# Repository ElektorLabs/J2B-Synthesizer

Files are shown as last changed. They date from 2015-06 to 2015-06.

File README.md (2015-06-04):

J2B Synthesizer
===============

An open source, open hardware music synthesizer for you to enjoy.
Based on an LPC1347 32-bit ARM Cortex-M3 microcontroller, this synthesizer
uses PWM to output sound. Originally based on and inspired by the Soulsby
Atmegatron.

Software is an LPCXpresso project.

Precompiled binaries are included for several synthesizers including
one drum machine. Uploading the firmware to the microcontroller is as simple 
as copying a file to a USB stick (this works on Windows only).

Licensed as described in the diverse licenses that may be found in the
repository. Roughly they state that you are allowed to do whatever you want
with this, as long as it remains for private use. However, you are allowed
to make money from music made with the J2B Synthesizer. 

More info:

www.elektor-labs.com/j2b-synthesizer

This is Elektor project 140182, published in Elektor Magazine, January 2015.

www.elektor-magazine.com/140182

www.elektor.com

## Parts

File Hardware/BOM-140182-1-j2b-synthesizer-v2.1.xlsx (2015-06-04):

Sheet: 140182-1
BOM::140182::J2B-synthesizer::v2.0
Description | Manufacturer | Reference | Footprint | Designation | Qnt | Farnell | Digikey | RS | Price | BOM for editors
Resistor |  |  |  |  | 89 |  |  |  |  | Resistor
resistor 0R 5% 0.1W | Multicomp | MC0805S8F0000T5E | R0805 | R1, R22, R26, R45, R49, R64, R68 | 7 | 2309112 |  |  |  | R1, R22, R26, R45, R49, R64, R68 = resistor 0R 5% 0.1W
resistor 10R 5% 0.1W | Multicomp | MC 0.1W 0805 5% 10R | M0805 | R76, R84 | 2 | 9333690 |  |  |  | R76, R84 = resistor 10R 5% 0.1W
resistor 33R 5% 0.1W | Multicomp | MC 0.1W 0805 5% 33R | R0805 | R3, R4 | 2 | 9334343 |  |  |  | R3, R4 = resistor 33R 5% 0.1W
resistor 47R 5% 0.25W | Multicomp | MCSR12X470 JTL | R1206 | R20 | 1 | 2074656 |  |  |  | R20 = resistor 47R 5% 0.25W
resistor 100R 5% 0.1W | Multicomp | MC01W08055100R | R0805 | R78, R97 | 2 | 9333703 |  |  |  | R78, R97 = resistor 100R 5% 0.1W
resistor 180R 5% 0.1W | Multicomp | MC01W08055180R | R0805 | R40, R83 | 2 | 9334025 |  |  |  | R40, R83 = resistor 180R 5% 0.1W
resistor 220R 5% 0.1W | Multicomp | MC01W08055220R | R0805 | R36, R38 | 2 | 9334130 |  |  |  | R36, R38 = resistor 220R 5% 0.1W
resistor 270R 5% 0.1W | Multicomp | MC01W08055270R | R0805 | R35, R37, R54, R85, R102 | 5 | 9334254 |  |  |  | R35, R37, R54, R85, R102 = resistor 270R 5% 0.1W
resistor 820R 5% 0.1W | Multicomp | MC01W08055820R | R0805 | R60, R89 | 2 | 9334890 |  |  |  | R60, R89 = resistor 820R 5% 0.1W
resistor 1k 5% 0.1W | Multicomp | MC 0.1W 0805 5% 1K | R0805 | R14, R80, R101 | 3 | 9333711 |  |  |  | R14, R80, R101 = resistor 1k 5% 0.1W
resistor 1k5 5% 0.1W | Multicomp | MC 0.1W 0805 5% 1K5 | R0805 | R16 | 1 | 9333924 |  |  |  | R16 = resistor 1k5 5% 0.1W
resistor 3k3 5% 0.1W | Multicomp | MC01W080553K3 | R0805 | R56, R87, R88, R90, R96, R100 | 6 | 9334360 |  |  |  | R56, R87, R88, R90, R96, R100 = resistor 3k3 5% 0.1W
resistor 4k7 5% 0.1W | Multicomp | MC 0.1W 0805 5% 4K7 | R0805 | R33, R34 | 2 | 9334580 |  |  |  | R33, R34 = resistor 4k7 5% 0.1W
resistor 6k8 5% 0.1W | Multicomp | MC01W080556K8 | R0805 | R55, R73, R86, R93 | 4 | 9334793 |  |  |  | R55, R73, R86, R93 = resistor 6k8 5% 0.1W
resistor 8k2 5% 0.1W | Multicomp | MC01W080558K2 | R0805 | R41, R81 | 2 | 9334904 |  |  |  | R41, R81 = resistor 8k2 5% 0.1W
resistor 10k 5% 0.1W | Multicomp | MC 0.1W 0805 5% 10K | R0805 | R5, R6, R7, R8, R9, R10, R11, R12, R21, R24, R25, R28, R29, R30, R31, R32, R44, R47, R48, R51, R52, R53, R57, R58, R63, R66, R67, R70, R71, R72, R74, R75, R91, R92 | 34 | 9333720 |  |  |  | R5, R6, R7, R8, R9, R10, R11, R12, R21, R24, R25, R28, R29, R30, R31, R32, R44, R47, R48, R51, R52, R53, R57, R58, R63, R66, R67, R70, R71, R72, R74, R75, R91, R92 = resistor 10k 5% 0.1W
resistor 82k 5% 0.1W | Multicomp | MC01W0805582K | R0805 | R39, R82 | 2 | 9334912 |  |  |  | R39, R82 = resistor 82k 5% 0.1W
resistor 100k 5% 0.1W | Multicomp | MC 0.1W 0805 5% 100K | R0805 | R2, R13, R59, R77, R79, R94, R98, R99 | 8 | 9333738 |  |  |  | R2, R13, R59, R77, R79, R94, R98, R99 = resistor 100k 5% 0.1W
resistor 1M 5% 0.1W | Multicomp | MC 0.1W 0805 5% 1M | R0805 | R17 | 1 | 9333746 |  |  |  | R17 = resistor 1M 5% 0.1W
Potentiometer 10k log stereo | Bourns | PTD902-2015F-A103 | POT-STEREO | P1 | 1 | 2396034 |  |  |  | P1 = Potentiometer 10k log stereo
NC |  |  |  | R15, R18, R19, R23, R27, R42, R43, R46, R50, R61, R62, R65, R69, R95 |  |  |  |  |  | R15, R18, R19, R23, R27, R42, R43, R46, R50, R61, R62, R65, R69, R95 = NC
Capacitor |  |  |  |  | 54 |  |  |  |  | Capacitor
capacitor 18pF NPO 50V | Kemet | C0805C180J5GACTU | C0805K | C4, C8, C17, C20 | 4 | 1414673 |  |  |  | C4, C8, C17, C20 = capacitor 18pF NPO 50V
capacitor 680pF NPO 50V | Multicomp | MC0805N681J101CT | C0805K | C29, C30, C39, C45, C46, C54 | 6 | 1759286 |  |  |  | C29, C30, C39, C45, C46, C54 = capacitor 680pF NPO 50V
capacitor 10nF X7R 50V | Kemet | C0805C103K5RACTU | C0805K | C6, C7, C9, C10, C12, C13, C14, C15, C18, C23, C24, C25, C26, C27, C31, C32, C33, C34, C43 | 19 | 1414662 |  |  |  | C6, C7, C9, C10, C12, C13, C14, C15, C18, C23, C24, C25, C26, C27, C31, C32, C33, C34, C43 = capacitor 10nF X7R 50V
capacitor 15nF X7R 50V | Multicomp | MC0805B153K500CT | C0805K | C28, C44 | 2 | 1759249 |  |  |  | C28, C44 = capacitor 15nF X7R 50V
capacitor 100nF X7R 50V | Kemet | C0805C104K5RACTU | C0805K | C1, C16, C22, C36, C48, C49 | 6 | 1414664 |  |  |  | C1, C16, C22, C36, C48, C49 = capacitor 100nF X7R 50V
capacitor 220nF X7R 50V | Kemet | C0805C224K5RACTU | C0805K | C38, C53 | 2 | 1288261 |  |  |  | C38, C53 = capacitor 220nF X7R 50V
capacitor 1uF X7R 10V | Multicomp | MC0805B105K100CT | C0805K | C19, C21 | 2 | 2320857 |  |  |  | C19, C21 = capacitor 1uF X7R 10V
capacitor tantalum 10uF 6.3V | AVX | TPSR106K006R1500 | 0805 | C5, C11, C35, C41, C42, C47, C50, C51, C55 | 9 | 1658721 |  |  |  | C5, C11, C35, C41, C42, C47, C50, C51, C55 = capacitor tantalum 10uF 6.3V
capacitor tantalum 100uF 6.3V | Vishay Sprague | TR3B107M6R3C1500 | B/3528-21R | C3, C37, C40, C52 | 4 | 1754048 |  |  |  | C3, C37, C40, C52 = capacitor tantalum 100uF 6.3V
NC |  |  | C0805K | C2 |  |  |  |  |  | C2 = NC
Inductor / Self |  |  |  |  | 3 |  |  |  |  | Inductor / Self
Ferrite bead, 0.21Ω, 0.6A | Murata | BLM21AG601SN1D | L0805 | L1, L2, L3 | 3 | 1515622 |  |  |  | L1, L2, L3 = Ferrite bead, 0.21Ω, 0.6A
Semiconductor |  |  |  |  | 24 |  |  |  |  | Semiconductor
BAT54C,215 | NXP | BAT54C,215 | SOT-23 | D1, D2, D3, D4, D5, D6, D7, D8, D9 | 9 | 1081192 |  |  |  | D1, D2, D3, D4, D5, D6, D7, D8, D9 = BAT54C,215
MBR0540T1G | ON Semiconductor | MBR0540T1G | SOD-123 | D10 | 1 | 9556923 |  |  |  | D10 = MBR0540T1G
LED, bi-color, red-green, CC, 5mm | Kingbright | L-59EGW | DUOLED-C-5MM | LED1, LED2 | 2 | 2001770 |  |  |  | LED1, LED2 = LED, bi-color, red-green, CC, 5mm
LED, red, 3mm | Multicomp | MCL034MT | EPP-LED-3MM | LED3 | 1 | 1581122 |  |  |  | LED3 = LED, red, 3mm
LPC1347FBD48 | NXP | LPC1347FBD48 | LQFP48 | IC2 | 1 | 2103477 |  | 791-8179 |  | IC2 = LPC1347FBD48
LD1117S33CTR | STMicroelectronics | LD1117S33CTR | SOT223 | IC1 | 1 | 1467779 |  |  |  | IC1 = LD1117S33CTR
BSS84P | Infineon | BSS84P | SOT-23 | T1, T2, T3, T4, T5, T6 | 6 | 1056526 |  |  |  | T1, T2, T3, T4, T5, T6 = BSS84P
MCP6004-I/SL | Microchip | MCP6004-I/SL | SOIC14 | IC3, IC4 | 2 | 1605572 |  |  |  | IC3, IC4 = MCP6004-I/SL
TDA1308T/N2 | NXP | TDA1308T/N2 | SOIC8 | IC5 | 1 | 1854038 |  |  |  | IC5 = TDA1308T/N2
Misc. |  |  |  |  | 17 |  |  |  |  | Misc.
header male 4 pin, 0.1" pitch vertical | Fisher Elektronik | SL1.025.4Z | through-hole 2.54 mm pitch single row | K1 | 1 | 9729038 |  |  |  | K1 = header male 4 pin, 0.1" pitch vertical
header male 8 pin, 0.1" pitch vertical | Fisher Elektronik | SL1.025.8Z | through-hole 2.54 mm pitch single row | K2 | 1 | 9729038 |  |  |  | K2 = header male 8 pin, 0.1" pitch vertical
Jack 3.5 mm, stereo | Lumberg | KLBR 4 | EPP-JACK-350 | K3 | 1 | 1217016 |  |  |  | K3 = Jack 3.5 mm, stereo
Mini USB-B shielded | Molex | 675031020 | 0.8" SMD Mini-USB-B | K4 | 1 | 1125348 |  |  |  | K4 = Mini USB-B shielded
Rotary encoder | Alps | EC12E2424407 | through-hole | S1, S2, S3, S4, S5, S6, S7, S8 | 8 | 1520813 |  |  |  | S1, S2, S3, S4, S5, S6, S7, S8 = Rotary encoder
Push button | Multimec | 3FTL6 | through-hole | S9 | 1 | 1132885 |  |  |  | S9 = Push button
LCD 2x16, I²C | Midas | MCCOG21605B6W-SPTLYI | LCD-I2C | LCD1 | 1 | 2063208 |  |  |  | LCD1 = LCD 2x16, I²C
crystal 12 MHz | IQD Frequency Products | LF A158E | HC49/SMD | X1 | 1 | 9713344 |  |  |  | X1 = crystal 12 MHz
Enclosure | Hammond | 1597DGY | n/a | BOX1 | 1 | 1876944 |  |  |  | BOX1 = Enclosure
PCB 140182-1-v2.1 | Elektor |  |  |  | 1 |  |  |  |  | PCB 140182-1-v2.1
3FTL6 |  |  | PUSHBUTTON_MULTIMEC | S1 |  |  |  |  |  | PUSHBUTTON_MULTIMEC
3FTL6 |  |  | PUSHBUTTON_MULTIMEC | S2 |  |  |  |  |  | PUSHBUTTON_MULTIMEC
3FTL6 |  |  | PUSHBUTTON_MULTIMEC | S3 |  |  |  |  |  | PUSHBUTTON_MULTIMEC
3FTL6 |  |  | PUSHBUTTON_MULTIMEC | S4 |  |  |  |  |  | PUSHBUTTON_MULTIMEC
3FTL6 |  |  | PUSHBUTTON_MULTIMEC | S5 |  |  |  |  |  | PUSHBUTTON_MULTIMEC
3FTL6 |  |  | PUSHBUTTON_MULTIMEC | S6 |  |  |  |  |  | PUSHBUTTON_MULTIMEC
3FTL6 |  |  | PUSHBUTTON_MULTIMEC | S7 |  |  |  |  |  | PUSHBUTTON_MULTIMEC
3FTL6 |  |  | PUSHBUTTON_MULTIMEC | S8 |  |  |  |  |  | PUSHBUTTON_MULTIMEC
3FTL6 |  |  | PUSHBUTTON_MULTIMEC | S9A |  |  |  |  |  | PUSHBUTTON_MULTIMEC
3FTL6 |  |  | PUSHBUTTON_MULTIMEC | S9B |  |  |  |  |  | PUSHBUTTON_MULTIMEC
3FTL6 |  |  | PUSHBUTTON_MULTIMEC | S10A |  |  |  |  |  | PUSHBUTTON_MULTIMEC
3FTL6 |  |  | PUSHBUTTON_MULTIMEC | S10B |  |  |  |  |  | PUSHBUTTON_MULTIMEC
3FTL6 |  |  | PUSHBUTTON_MULTIMEC | S11A |  |  |  |  |  | PUSHBUTTON_MULTIMEC
3FTL6 |  |  | PUSHBUTTON_MULTIMEC | S11B |  |  |  |  |  | PUSHBUTTON_MULTIMEC
3FTL6 |  |  | PUSHBUTTON_MULTIMEC | S12A |  |  |  |  |  | PUSHBUTTON_MULTIMEC
3FTL6 |  |  | PUSHBUTTON_MULTIMEC | S12B |  |  |  |  |  | PUSHBUTTON_MULTIMEC
EC12E_SW |  |  | ALPS_EC12E_SW | S13 |  |  |  |  |  | EC12E_SW
EC12E_SW |  |  | ALPS_EC12E_SW | S14 |  |  |  |  |  | EC12E_SW
EC12E_SW |  |  | ALPS_EC12E_SW | S15 |  |  |  |  |  | EC12E_SW
EC12E_SW |  |  | ALPS_EC12E_SW | S16 |  |  |  |  |  | EC12E_SW
EC12E_SW |  |  | ALPS_EC12E_SW | S17 |  |  |  |  |  | EC12E_SW
EC12E_SW |  |  | ALPS_EC12E_SW | S18 |  |  |  |  |  | EC12E_SW
EC12E_SW |  |  | ALPS_EC12E_SW | S19A |  |  |  |  |  | EC12E_SW
EC12E_SW |  |  | ALPS_EC12E_SW | S19B |  |  |  |  |  | EC12E_SW
EC12E_SW |  |  | ALPS_EC12E_SW | S20A |  |  |  |  |  | EC12E_SW
EC12E_SW |  |  | ALPS_EC12E_SW | S20B |  |  |  |  |  | EC12E_SW
EC12E_SW |  |  | ALPS_EC12E_SW | S21A |  |  |  |  |  | EC12E_SW
EC12E_SW |  |  | ALPS_EC12E_SW | S21B |  |  |  |  |  | EC12E_SW
ZXM61P03F |  |  | SOT-23 | T1 |  |  |  |  |  | PMOSSOT23
ZXM61P03F |  |  | SOT-23 | T2 |  |  |  |  |  | PMOSSOT23
ZXM61P03F |  |  | SOT-23 | T3 |  |  |  |  |  | PMOSSOT23
ZXM61P03F |  |  | SOT-23 | T4 |  |  |  |  |  | PMOSSOT23
ZXM61P03F |  |  | SOT-23 | T5 |  |  |  |  |  | PMOSSOT23
TPSQPAD1-13 |  |  | P1-13 | TP1 |  |  |  |  |  | TPSQPAD1-13
TPSQPAD1-13 |  |  | P1-13 | TP2 |  |  |  |  |  | TPSQPAD1-13
12 MHz |  |  | SM49 | X1 |  |  |  |  |  | CRYSTALSM49

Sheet: 140182-2
BOM 140182-2 J2B-synthesizer MIDI board
Description | Manufacturer | Reference | Footprint | Designation | Qnt | Farnell | Digikey | RS | Price | BOM for editors
Resistor |  |  |  |  | 4 |  |  |  |  | Resistor
resistor 220R 5% 0.1W | Multicomp | MC01W08055220R | R0805 | R201, R202, R203 | 3 | 9334130 |  |  |  | R201, R202, R203 = resistor 220R 5% 0.1W
resistor 1k 5% 0.1W | Multicomp | MC 0.1W 0805 5% 1K | R0805 | R204 | 1 | 9333711 |  |  |  | R204 = resistor 1k 5% 0.1W
Semiconductor |  |  |  |  | 2 |  |  |  |  | Semiconductor
BAT54C,215 | NXP | BAT54C,215 | SOT-23 | D201 | 1 | 1081192 |  |  |  | D201 = BAT54C,215
CNY17-3 | Vishay | CNY17-3 | EPP-DIP-6 | IC201 | 1 | 1652511 |  | n/a |  | IC201 = CNY17-3
Misc. |  |  |  |  | 4 |  |  |  |  | Misc.
header female 4 pin, 0.1" pitch vertical | Fisher Elektronik |  | through-hole 2.54 mm pitch single row | K201 | 1 |  |  |  |  | K201 = header female 4 pin, 0.1" pitch vertical
5-way DIN connector, 180 deg, female | Hirschmann | MAB5SH | MAB5SH | K202, K203 | 2 | 1944987 |  |  |  | K202, K203 = 5-way DIN connector, 180 deg, female
PCB 140182-2-v2.0 | Elektor |  |  |  | 1 |  |  |  |  | PCB 140182-2-v2.0

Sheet: 140182 kit
BOM 140182 J2B-synthesizer
Description | Manufacturer | Reference | Footprint | Designation | Qnt | Farnell | Digikey | RS | Price
Enclosure | Hammond | 1597DGY |  |  | 1 | 1876944
Board 140182-1 | Elektor |  |  |  | 1
Board 140182-2 | Elektor |  |  |  | 1
Knob, Grey/White, 16 mm high, 13,2 mm diameter, 6 mm shaft diameter, D-shaft | Multicomp | CR-R4-5 |  |  | 2 | 1440010
Knob, Black/White, 16 mm high, 13,2 mm diameter, 6 mm shaft diameter, D-shaft | Multicomp | CR-R4-7 |  |  | 6 | 1440012
Knob, Black/White, D-shaft | Multicomp | CR-BA-7C6-180D |  |  | 1 | 1441142
Pushbutton cap, 7.5 mm high, 10 mm diameter | Multimec | 1D09 |  |  | 1 | 1132886

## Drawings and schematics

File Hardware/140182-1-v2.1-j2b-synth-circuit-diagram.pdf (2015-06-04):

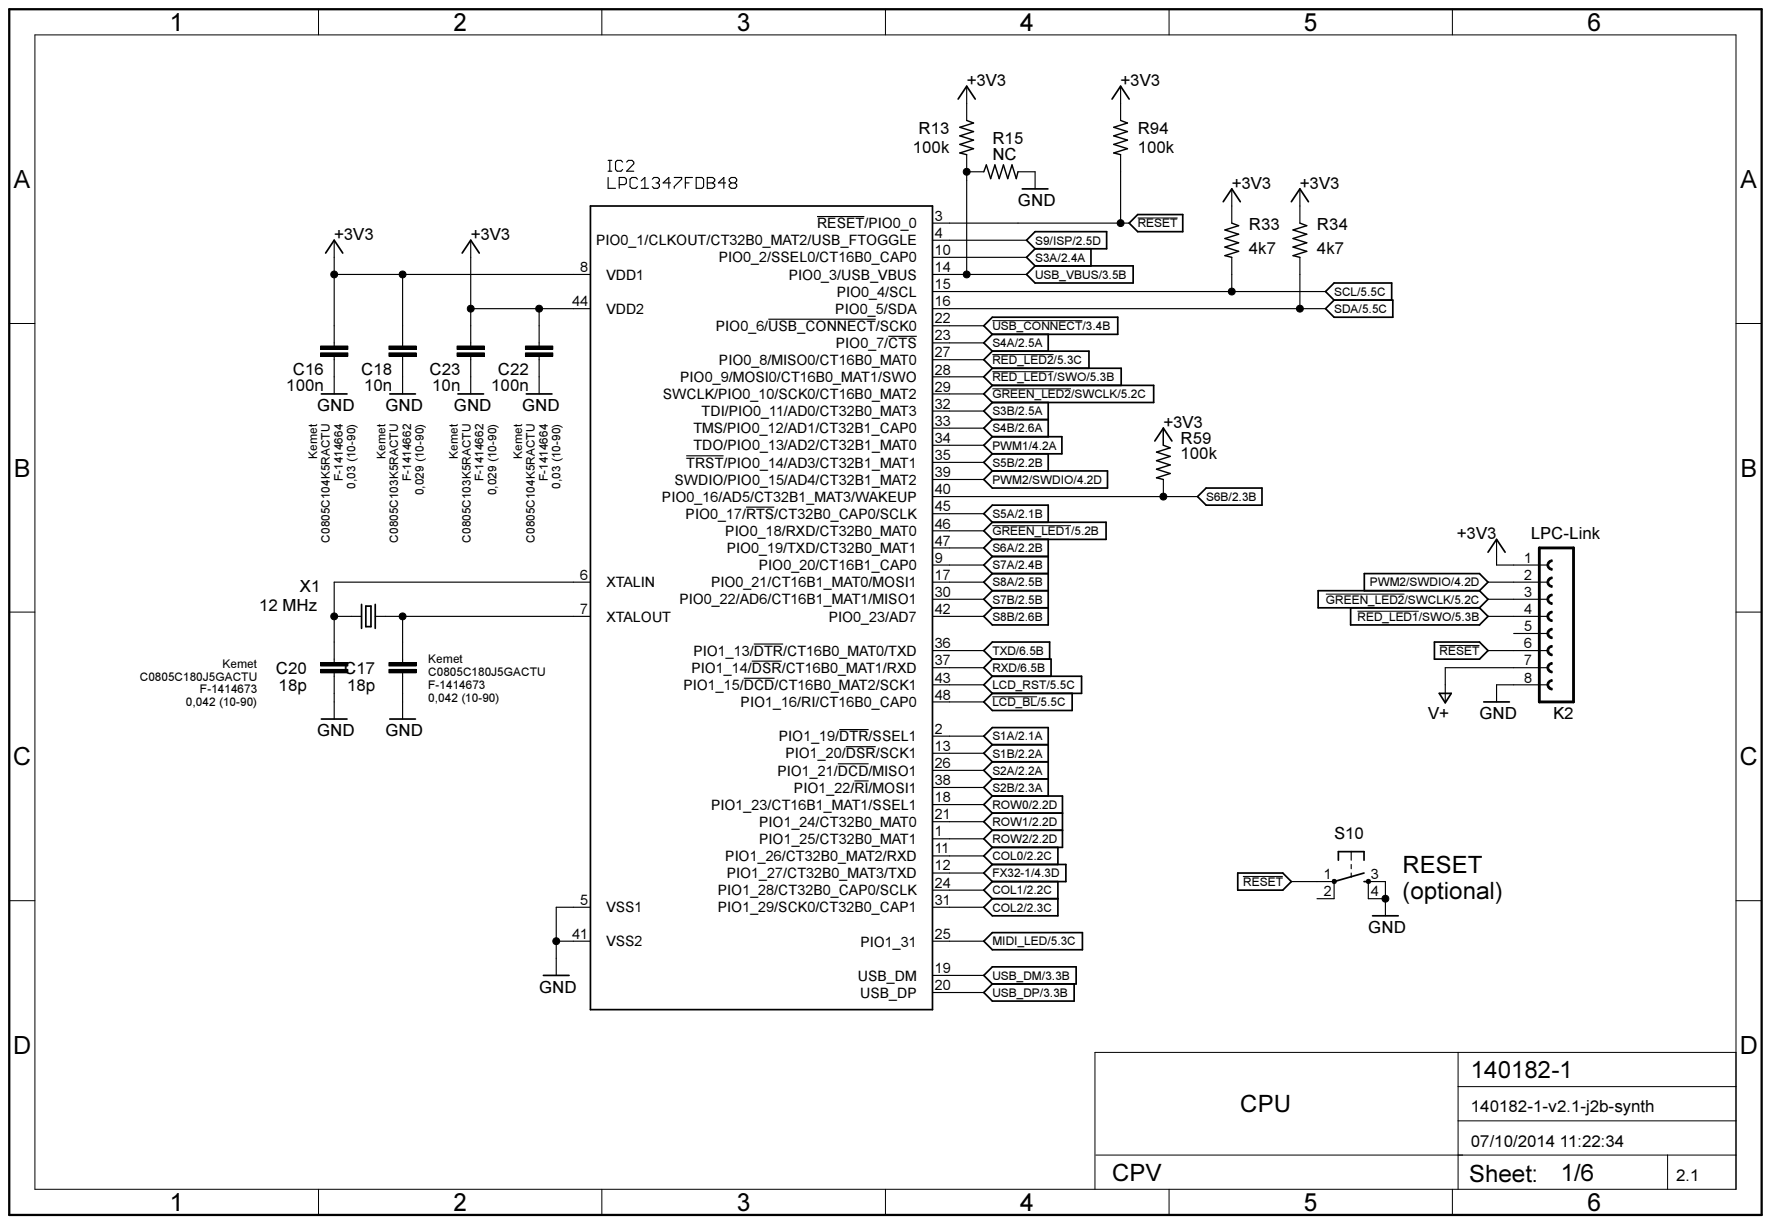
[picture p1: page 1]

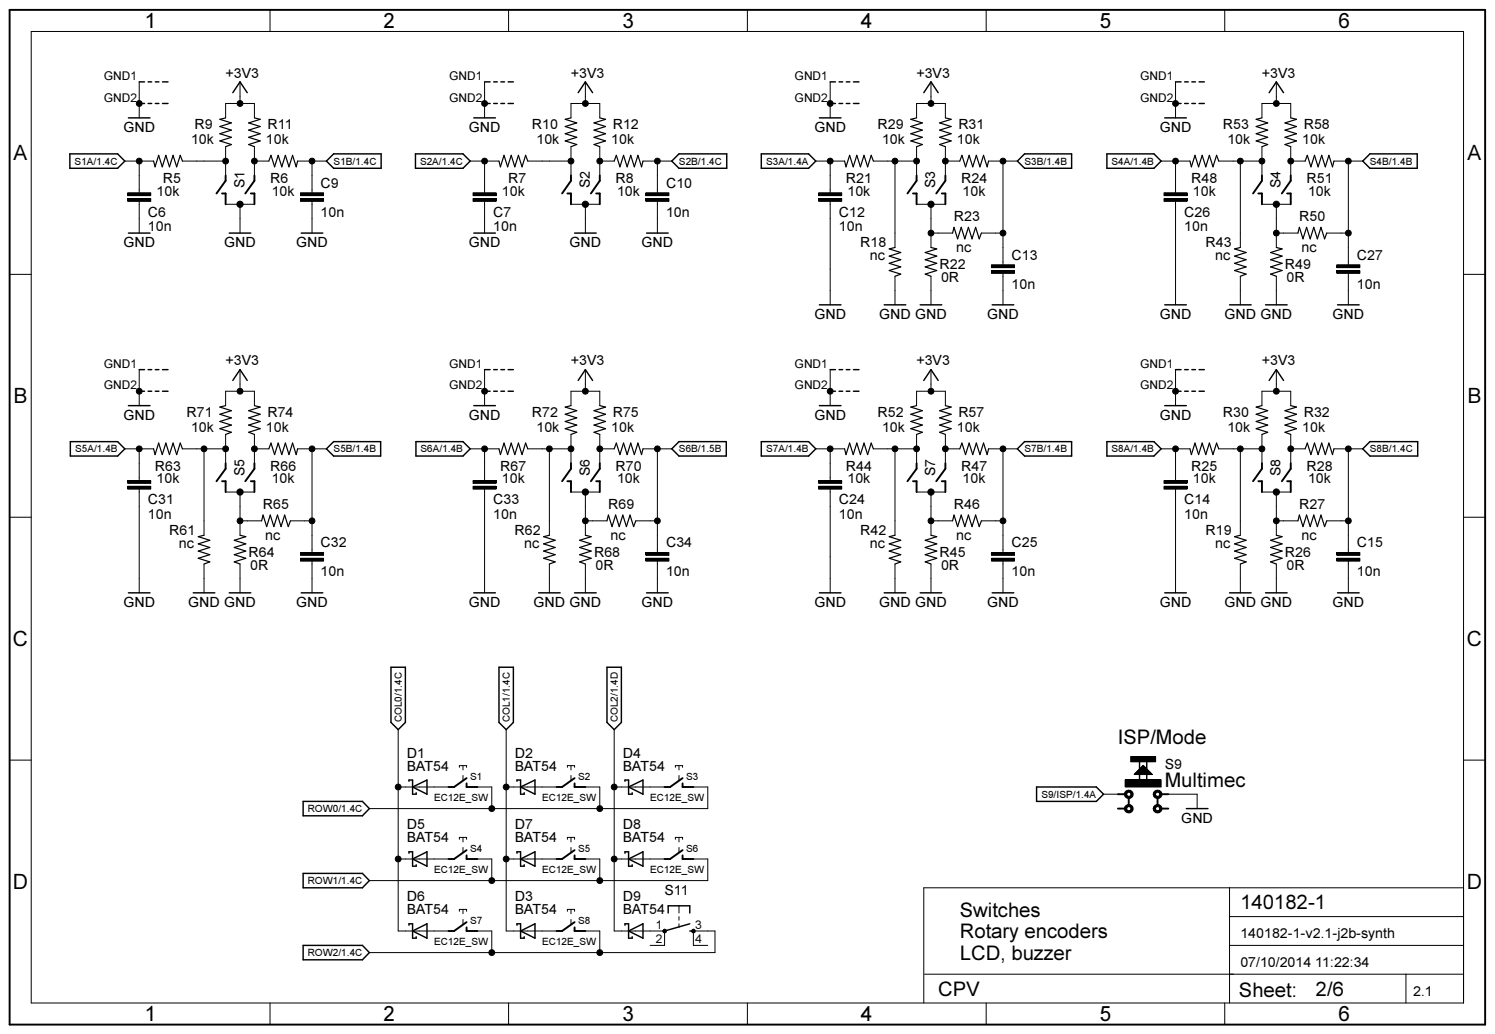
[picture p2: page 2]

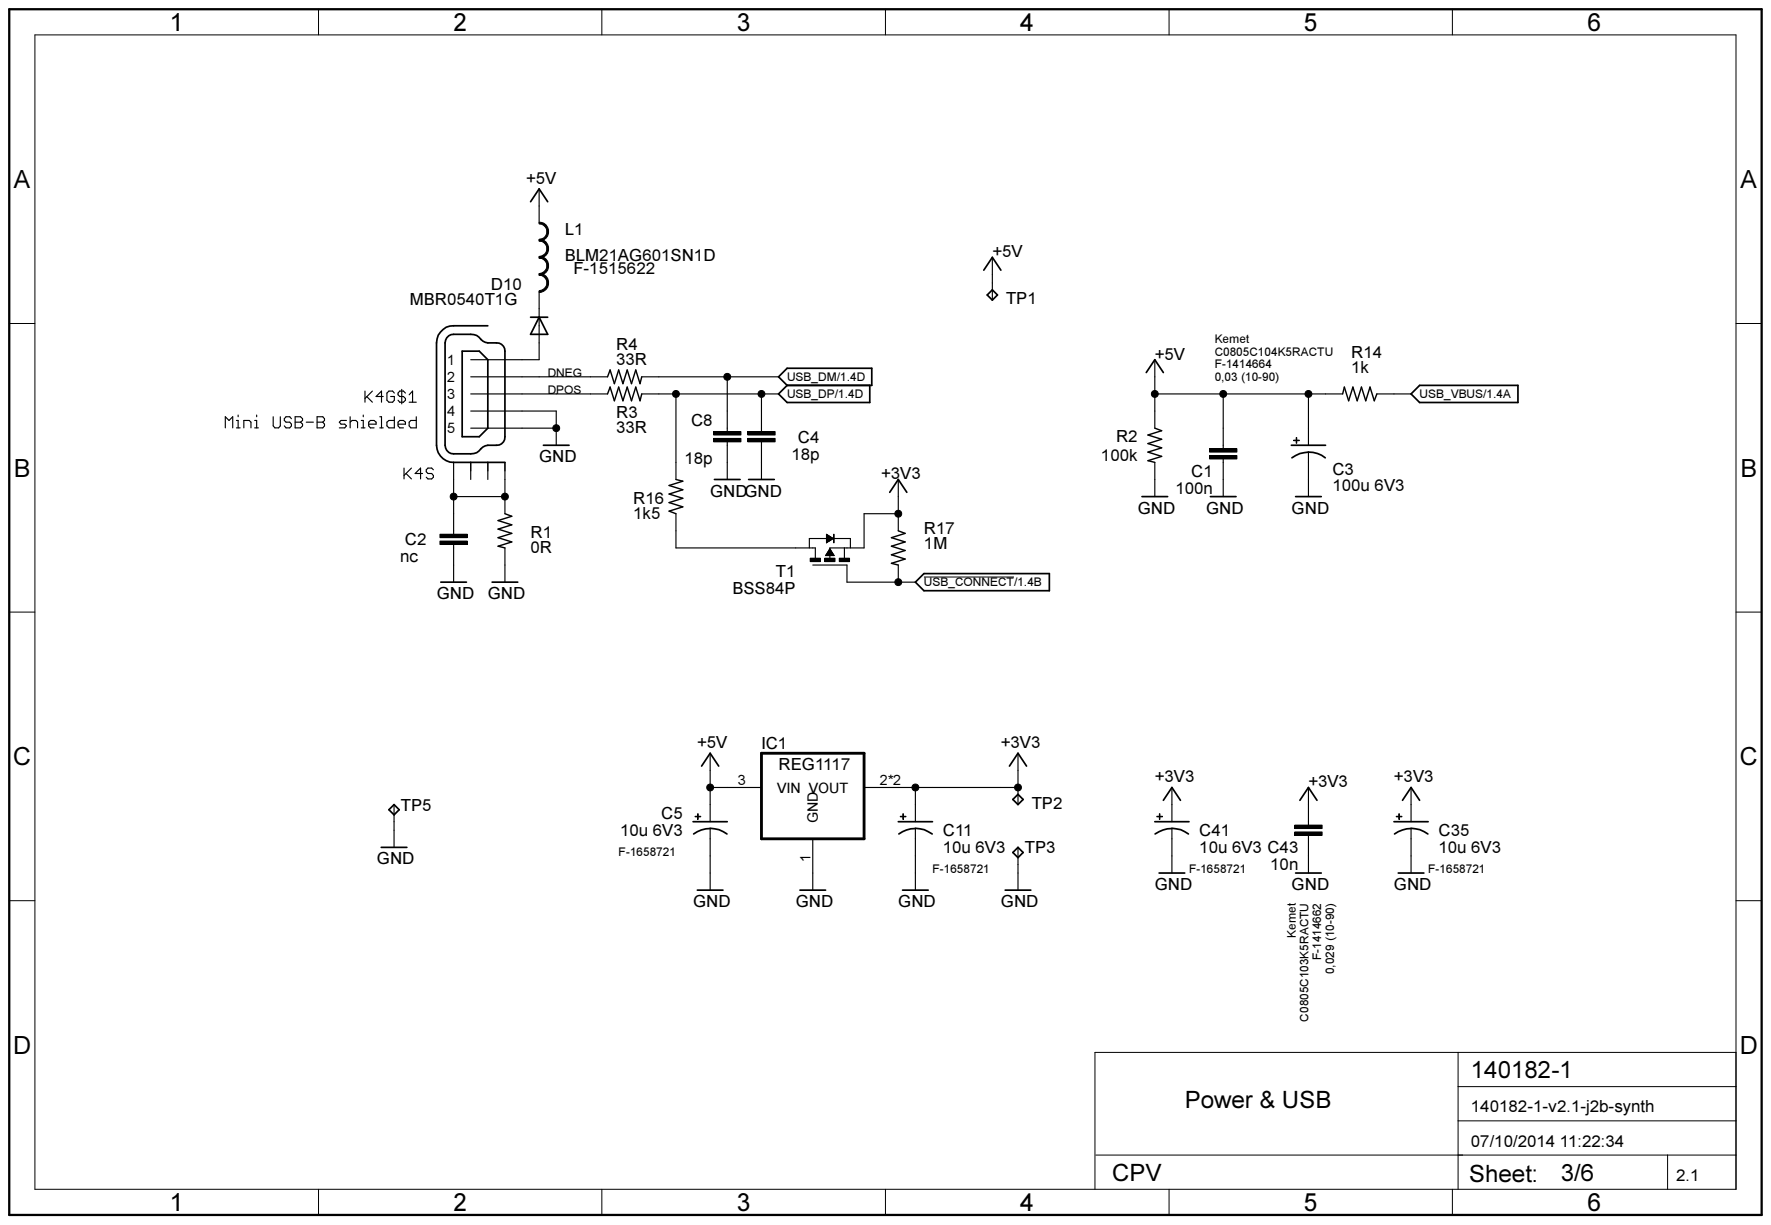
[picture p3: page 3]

88k7 | 3k48 | 8k45 | 732R | 1k1

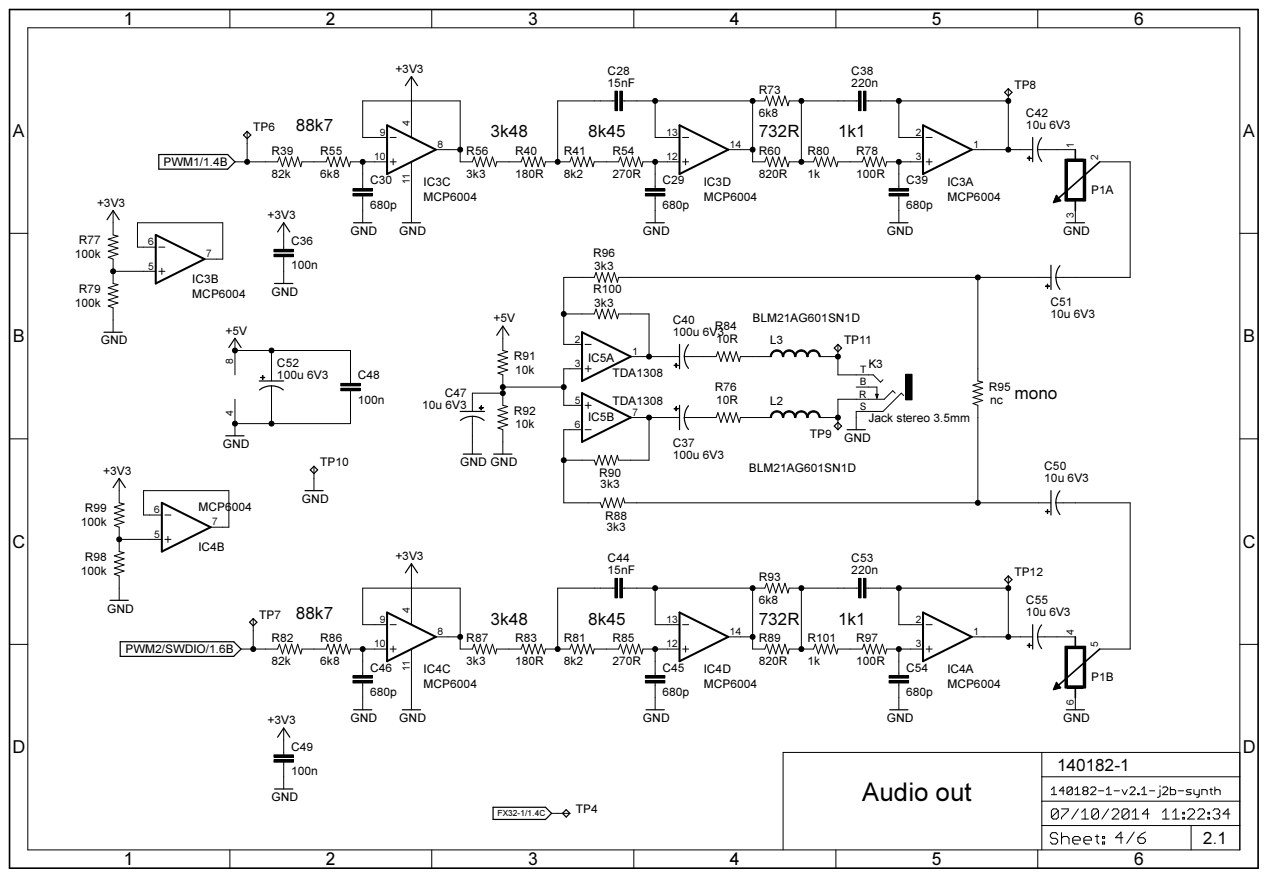
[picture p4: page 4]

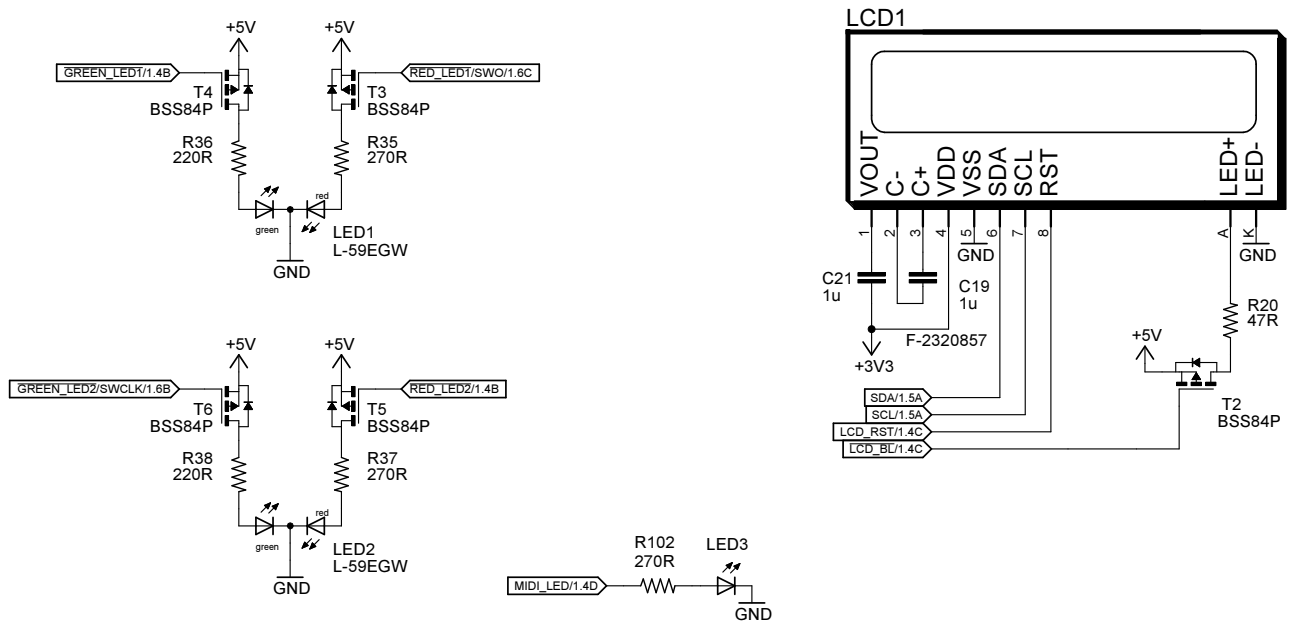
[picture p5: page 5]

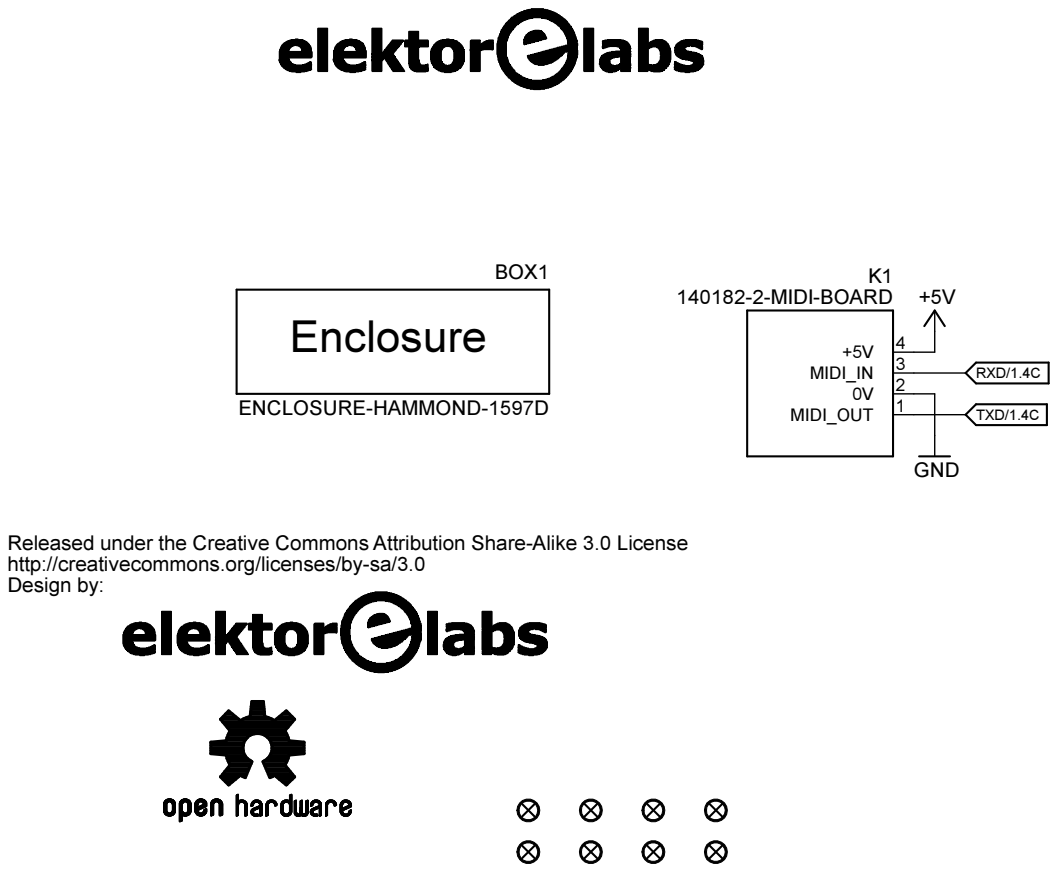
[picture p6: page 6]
Fiducials & mechanics; MIDI interface; ENCLOSURE-HAMMOND-1597D; 140182-2-MIDI-BOARD; GND; BOX1; MIDI_OUT; 2 MIDI_IN; TXD/1.4C; RXD/1.4C; Enclosure

Released under the Creative Commons Attribution Share-Alike 3.0 License
http://creativecommons.org/licenses/by-sa/3.0
Design by:

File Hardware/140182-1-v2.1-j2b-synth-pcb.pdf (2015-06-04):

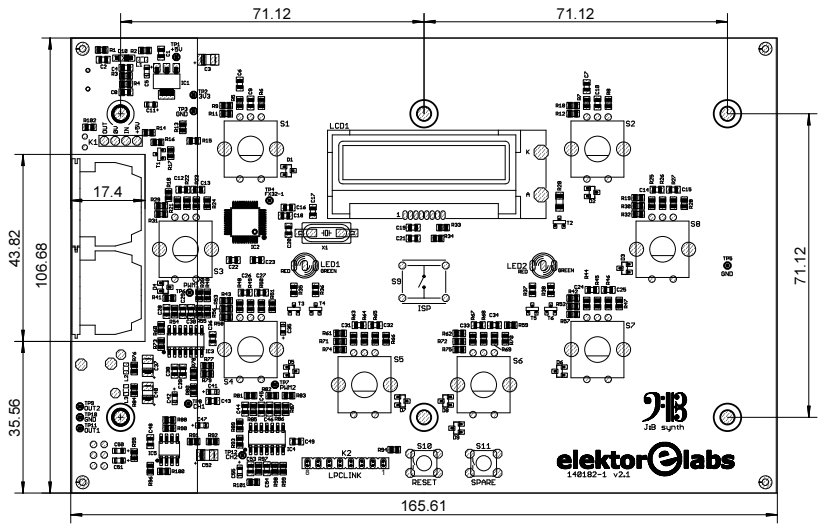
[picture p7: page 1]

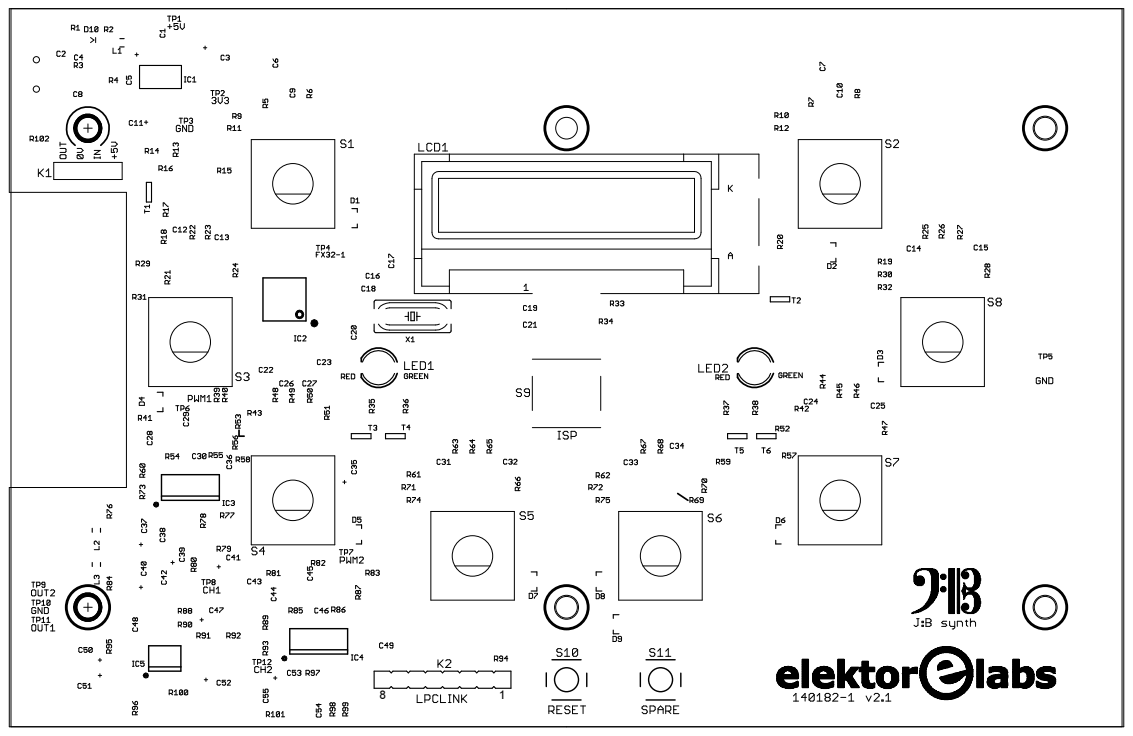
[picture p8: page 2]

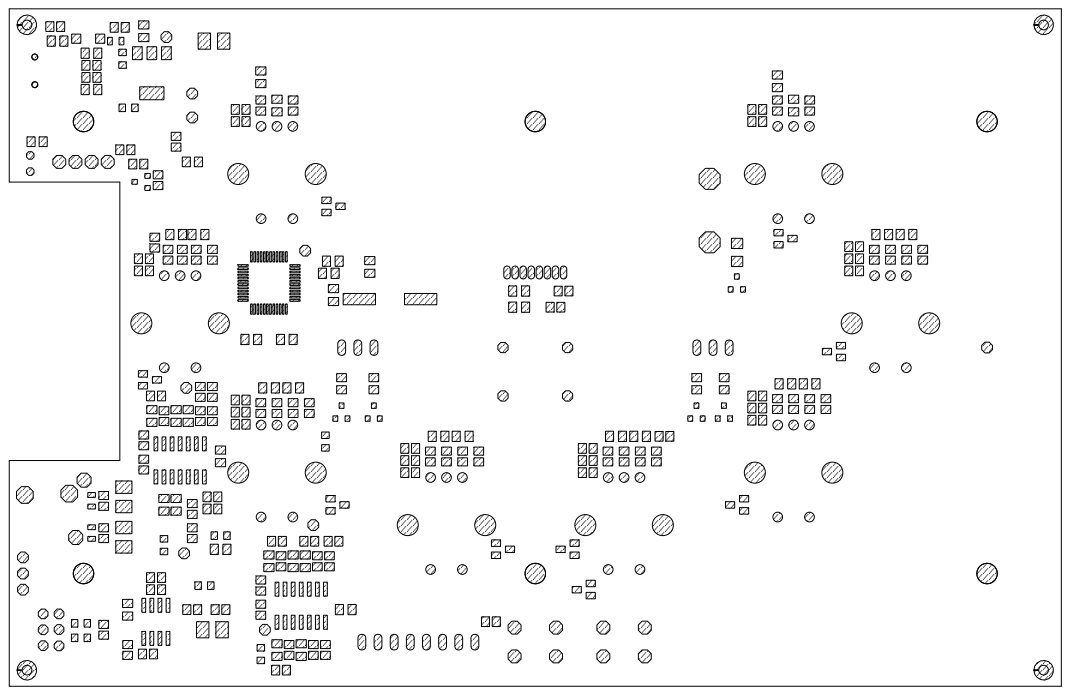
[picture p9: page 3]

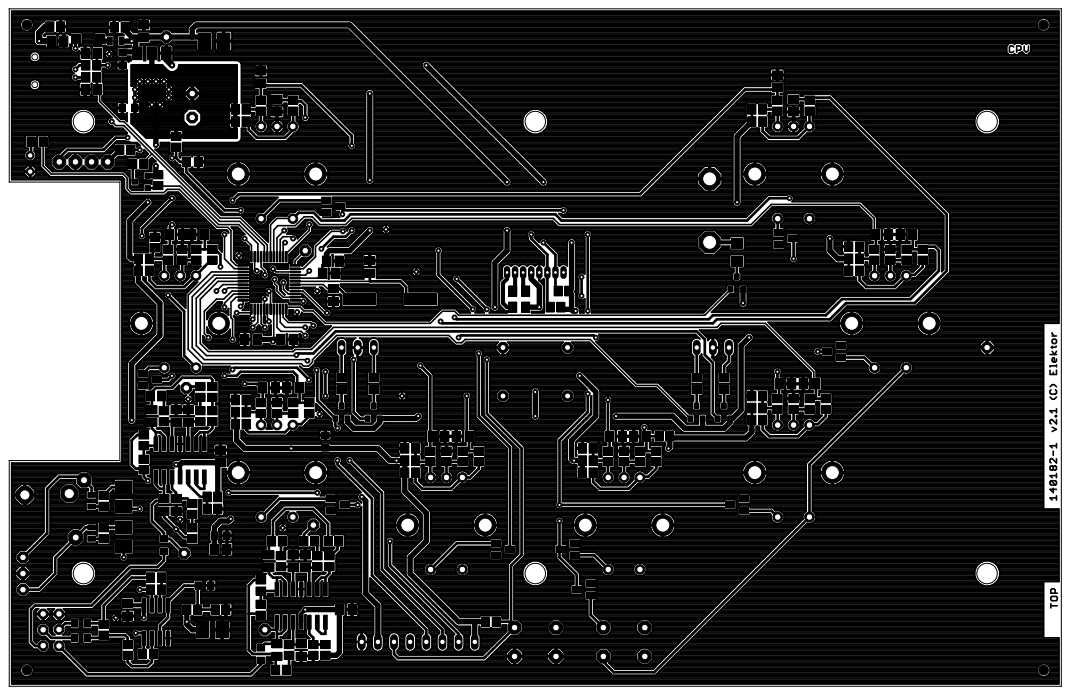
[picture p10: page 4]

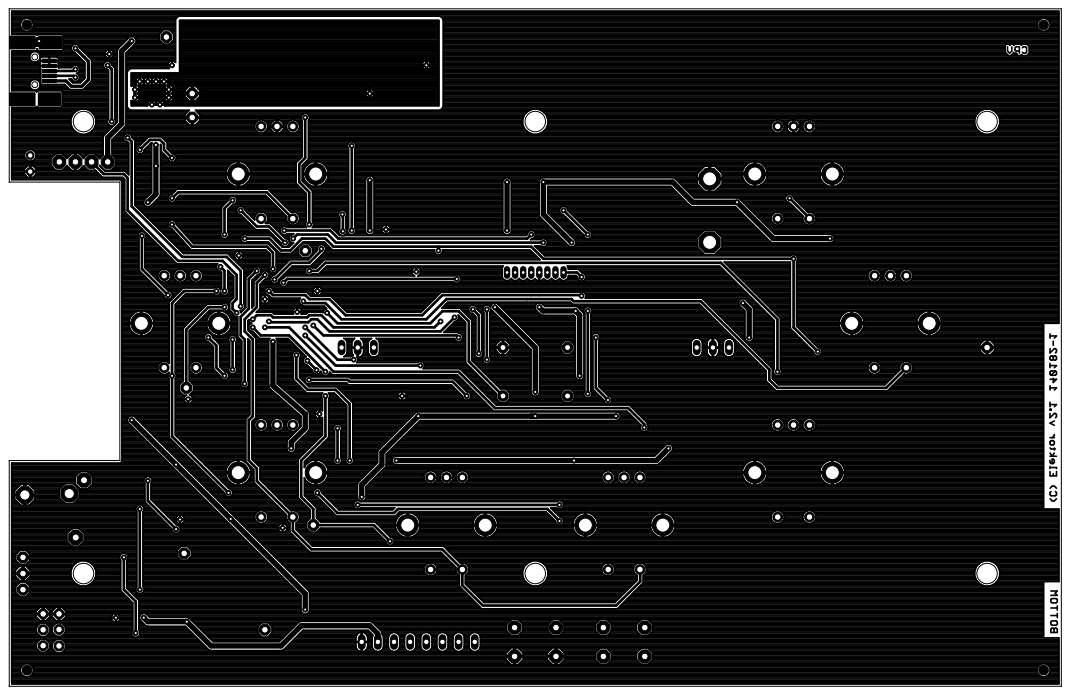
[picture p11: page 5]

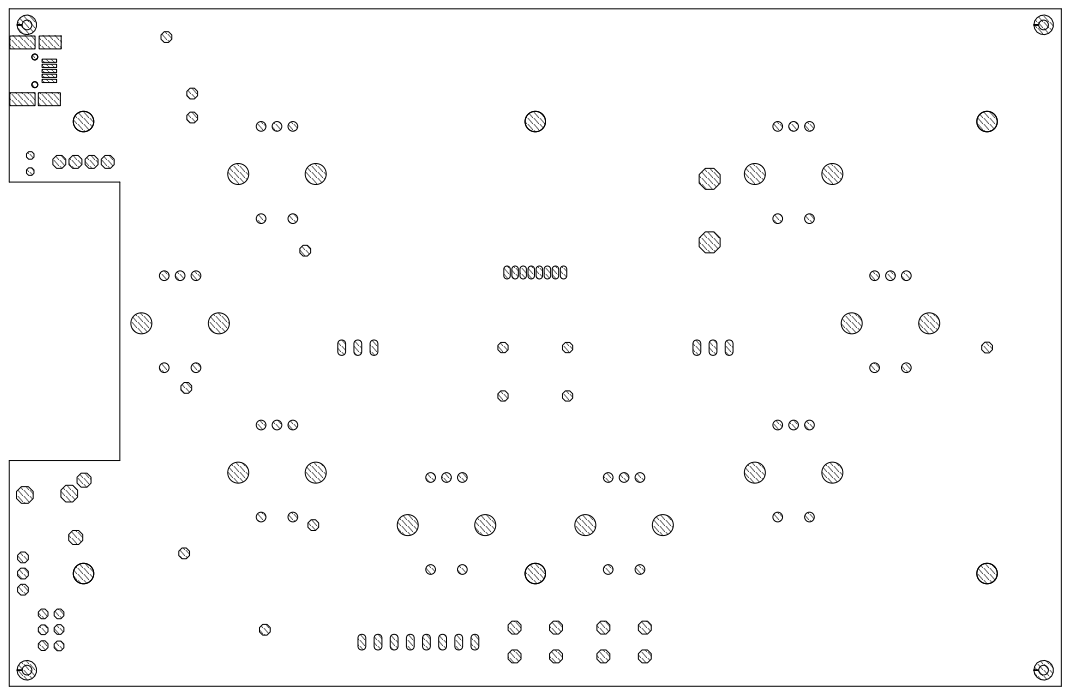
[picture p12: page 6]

Designed by:

http://creativecommons.org/licenses/by-sa/3.0

Released under the Creative Commons Attribution Share-Alike 3.0 License

Designed by:

Released under the Creative Commons Attribution Share-Alike 3.0 License

http://creativecommons.org/licenses/by-sa/3.0


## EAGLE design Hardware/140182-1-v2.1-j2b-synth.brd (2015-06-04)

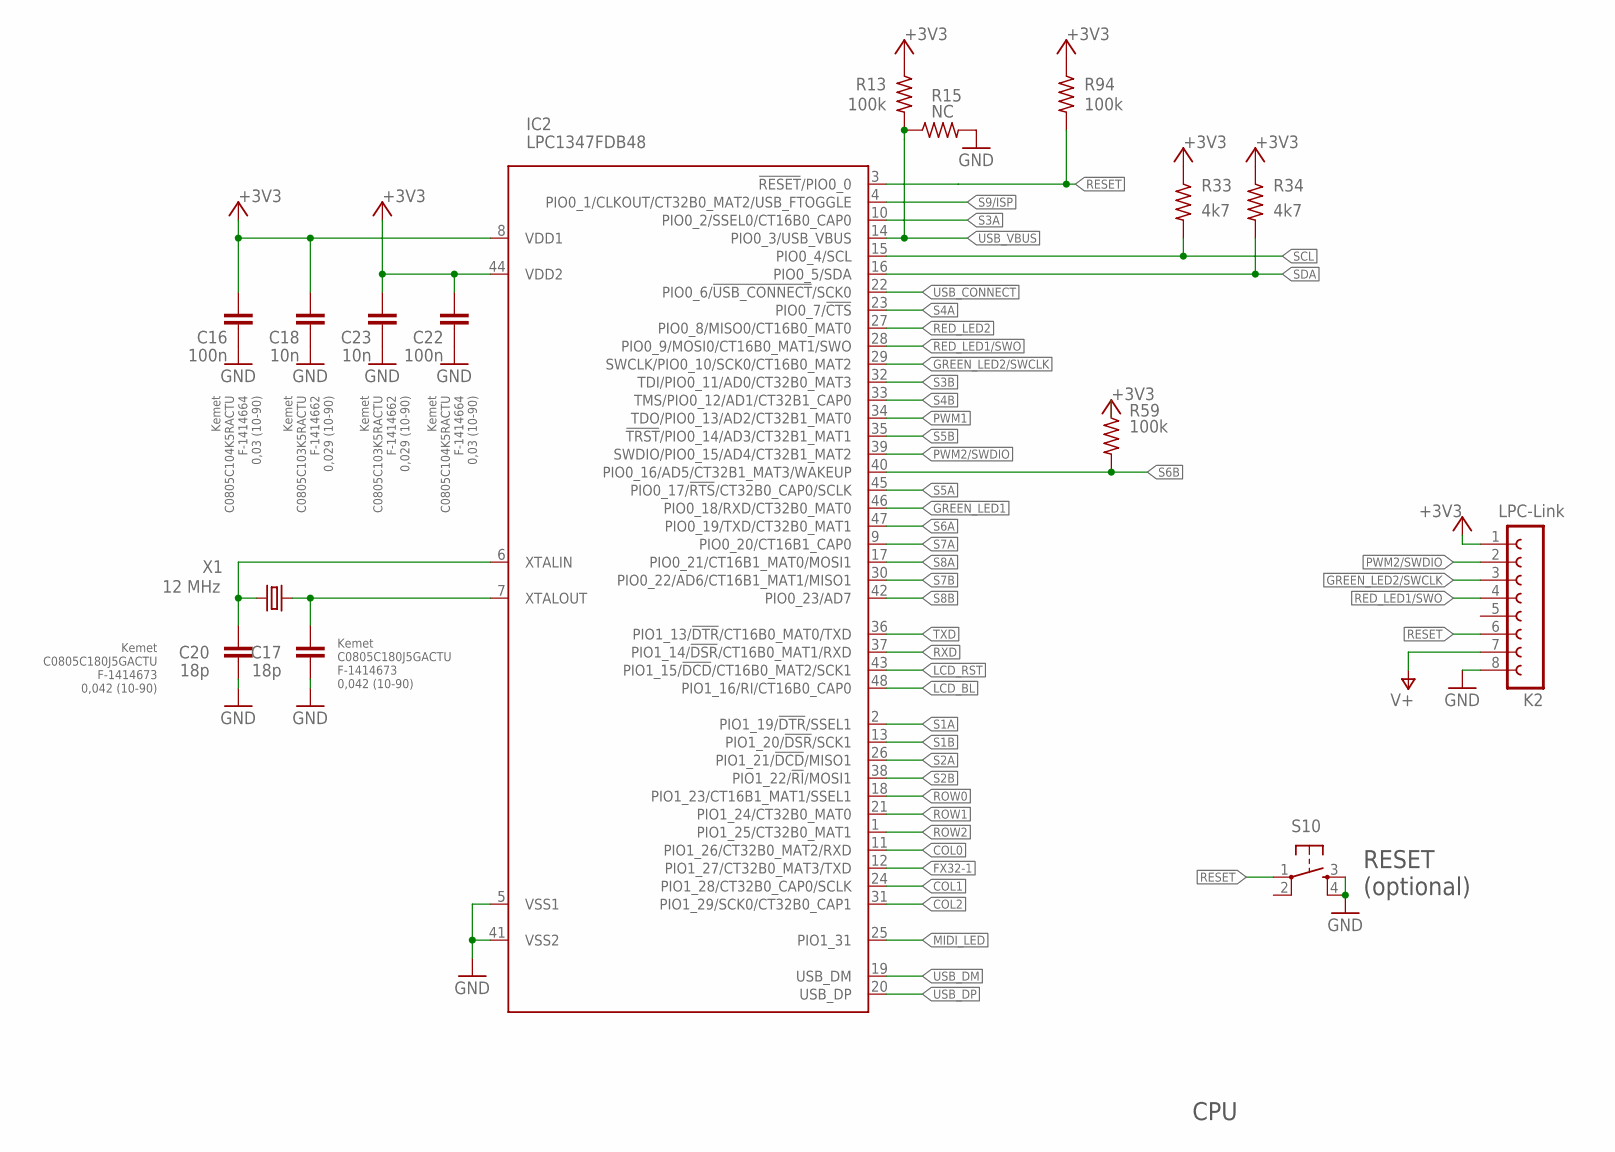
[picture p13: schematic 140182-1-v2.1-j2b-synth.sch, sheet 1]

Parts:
C16, C22: 100n; C0805K; FARNELL F-1414664
C17, C20: 18p; C0805K; FARNELL F-1414673
C18, C23: 10n; C0805K; FARNELL F-1414662
IC2: LPC1347FDB48; LQFP48
K2: LPC-Link; FE08
R13, R59, R94: 100k; R0805; FARNELL F-9333738
R15: NC; R0805
R33, R34: 4k7; R0805; FARNELL F-9334580
S10: S-TACTILE-6X6-PTH; EPP-S-TACT-6X6
X1: 12 MHz; SM49

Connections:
!GREEN_LED1!: IC2.46 (PIO0_18/RXD/CT32B0_MAT0); also elsewhere on the board
!GREEN_LED2!/SWCLK: IC2.29 (SWCLK/PIO0_10/SCK0/CT16B0_MAT2), K2.3; also elsewhere on the board
!LCD_BL: IC2.48 (PIO1_16/RI/CT16B0_CAP0); also elsewhere on the board
!RED_LED1!/SWO: IC2.28 (PIO0_9/MOSI0/CT16B0_MAT1/SWO), K2.4; also elsewhere on the board
!RED_LED2: IC2.27 (PIO0_8/MISO0/CT16B0_MAT0); also elsewhere on the board
!RESET: IC2.3 (!RESET!/PIO0_0), K2.6, R94.2, S10.1
!USB_CONNECT: IC2.22 (PIO0_6/!USB_CONNECT!/SCK0); also elsewhere on the board
+3V3: C16.2, C18.2, C22.2, C23.2, IC2.8 (VDD1), IC2.44 (VDD2), K2.1, R13.1, R33.1, R34.1, R59.1, R94.1; also elsewhere on the board
+5V: K2.7; also elsewhere on the board
COL0: IC2.11 (PIO1_26/CT32B0_MAT2/RXD); also elsewhere on the board
COL1: IC2.24 (PIO1_28/CT32B0_CAP0/SCLK); also elsewhere on the board
COL2: IC2.31 (PIO1_29/SCK0/CT32B0_CAP1); also elsewhere on the board
FX32-1: IC2.12 (PIO1_27/CT32B0_MAT3/TXD); also elsewhere on the board
GND: C16.1, C17.1, C18.1, C20.1, C22.1, C23.1, IC2.5 (VSS1), IC2.41 (VSS2), K2.8, R15.2, S10.3, S10.4; also elsewhere on the board
LCD_RST: IC2.43 (PIO1_15/!DCD!/CT16B0_MAT2/SCK1); also elsewhere on the board
MIDI_LED: IC2.25 (PIO1_31); also elsewhere on the board
unnamed: C20.2, IC2.6 (XTALIN), X1.1
unnamed: C17.2, IC2.7 (XTALOUT), X1.2
PWM1: IC2.34 (TDO/PIO0_13/AD2/CT32B1_MAT0); also elsewhere on the board
PWM2/SWDIO: IC2.39 (SWDIO/PIO0_15/AD4/CT32B1_MAT2), K2.2; also elsewhere on the board
ROW0: IC2.18 (PIO1_23/CT16B1_MAT1/SSEL1); also elsewhere on the board
ROW1: IC2.21 (PIO1_24/CT32B0_MAT0); also elsewhere on the board
ROW2: IC2.1 (PIO1_25/CT32B0_MAT1); also elsewhere on the board
RXD: IC2.37 (PIO1_14/!DSR!/CT16B0_MAT1/RXD); also elsewhere on the board
S1A: IC2.2 (PIO1_19/!DTR!/SSEL1); also elsewhere on the board
S1B: IC2.13 (PIO1_20/!DSR!/SCK1); also elsewhere on the board
S2A: IC2.26 (PIO1_21/!DCD!/MISO1); also elsewhere on the board
S2B: IC2.38 (PIO1_22/!RI!/MOSI1); also elsewhere on the board
S3A: IC2.10 (PIO0_2/SSEL0/CT16B0_CAP0); also elsewhere on the board
S3B: IC2.32 (TDI/PIO0_11/AD0/CT32B0_MAT3); also elsewhere on the board
S4A: IC2.23 (PIO0_7/!CTS); also elsewhere on the board
S4B: IC2.33 (TMS/PIO0_12/AD1/CT32B1_CAP0); also elsewhere on the board
S5A: IC2.45 (PIO0_17/!RTS!/CT32B0_CAP0/SCLK); also elsewhere on the board
S5B: IC2.35 (!TRST!/PIO0_14/AD3/CT32B1_MAT1); also elsewhere on the board
S6A: IC2.47 (PIO0_19/TXD/CT32B0_MAT1); also elsewhere on the board
S6B: IC2.40 (PIO0_16/AD5/CT32B1_MAT3/WAKEUP), R59.2; also elsewhere on the board
S7A: IC2.9 (PIO0_20/CT16B1_CAP0); also elsewhere on the board
S7B: IC2.30 (PIO0_22/AD6/CT16B1_MAT1/MISO1); also elsewhere on the board
S8A: IC2.17 (PIO0_21/CT16B1_MAT0/MOSI1); also elsewhere on the board
S8B: IC2.42 (PIO0_23/AD7); also elsewhere on the board
S9/ISP: IC2.4 (PIO0_1/CLKOUT/CT32B0_MAT2/USB_FTOGGLE); also elsewhere on the board
SCL: IC2.15 (PIO0_4/SCL), R33.2; also elsewhere on the board
SDA: IC2.16 (PIO0_5/SDA), R34.2; also elsewhere on the board
TXD: IC2.36 (PIO1_13/!DTR!/CT16B0_MAT0/TXD); also elsewhere on the board
USB_DM: IC2.19 (USB_DM); also elsewhere on the board
USB_DP: IC2.20 (USB_DP); also elsewhere on the board
USB_VBUS: IC2.14 (PIO0_3/USB_VBUS), R13.2, R15.1; also elsewhere on the board

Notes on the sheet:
CPU
RESET (optional)

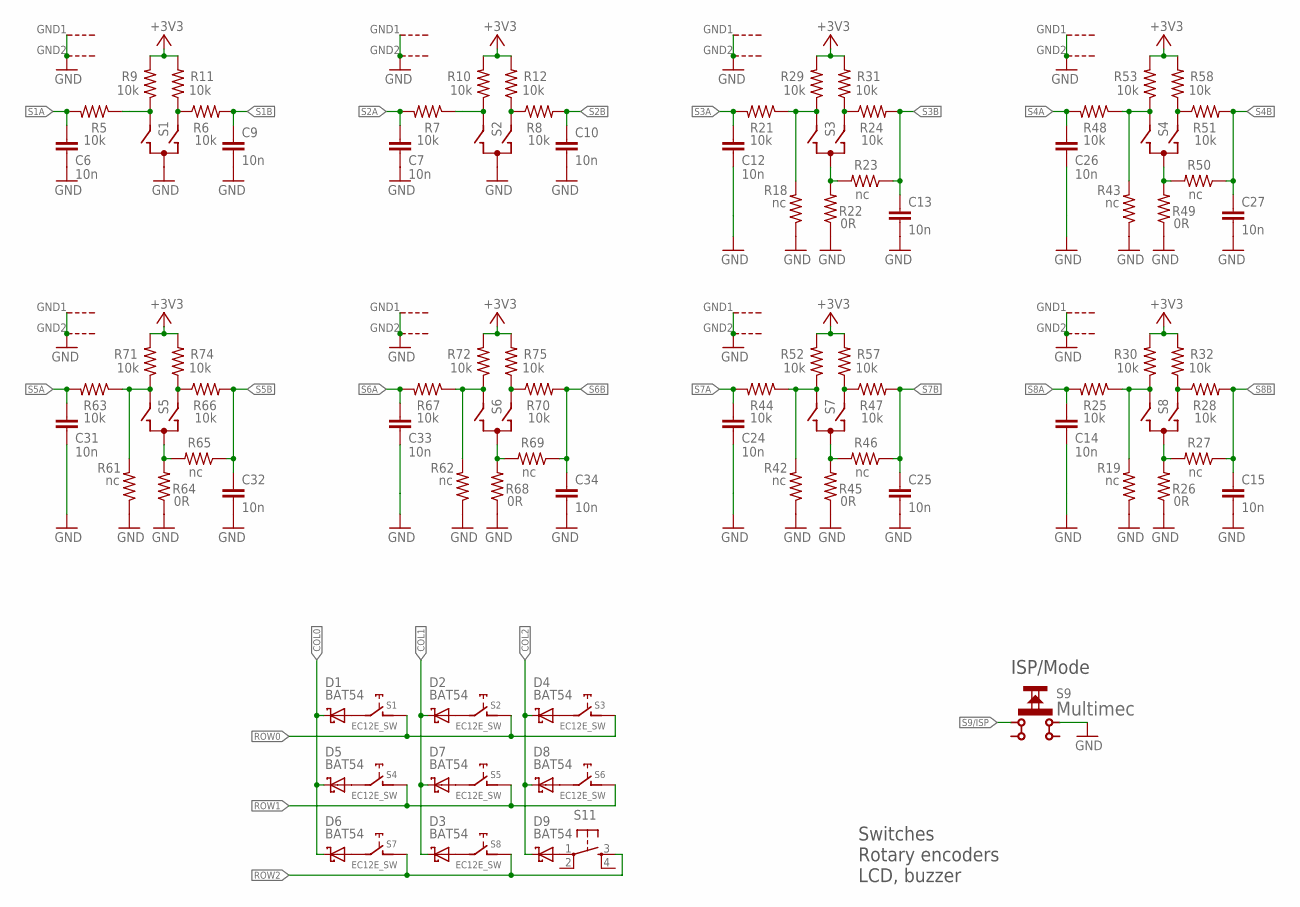
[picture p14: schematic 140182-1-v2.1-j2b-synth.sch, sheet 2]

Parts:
C6, C7, C9, C10, C12, C13, C14, C15, C24, C25, C26, C27, C31, C32, C33, C34: 10n; C0805K
D1, D2, D3, D4, D5, D6, D7, D8, D9: BAT54; SOT23
R5, R6, R7, R8, R21, R24, R25, R28, R44, R47, R48, R51, R63, R66, R67, R70: 10k; R0805; FARNELL F-9333711
R9, R10, R11, R12, R29, R30, R31, R32, R52, R53, R57, R58, R71, R72, R74, R75: 10k; R0805; FARNELL F-
R18, R19, R23, R27, R42, R43, R46, R50, R61, R62, R65, R69: nc; R0805; FARNELL F-9333711
R22, R26, R45, R49, R64, R68: 0R; R0805; FARNELL F-9333711
S1, S2, S3, S4, S5, S6, S7, S8: EC12E_SW; ALPS_EC12E_SW
S9: Multimec; PUSHBUTTON_MULTIMEC
S11: S-TACTILE-6X6-PTH; EPP-S-TACT-6X6

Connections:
+3V3: R9.2, R10.2, R11.2, R12.2, R29.2, R30.2, R31.2, R32.2, R52.2, R53.2, R57.2, R58.2, R71.2, R72.2, R74.2, R75.2; also elsewhere on the board
COL0: D1.3 (C), D5.3 (C), D6.3 (C); also elsewhere on the board
COL1: D2.3 (C), D3.3 (C), D7.3 (C); also elsewhere on the board
COL2: D4.3 (C), D8.3 (C), D9.3 (C); also elsewhere on the board
GND: C6.1, C7.1, C9.1, C10.1, C12.1, C13.1, C14.1, C15.1, C24.1, C25.1, C26.1, C27.1, C31.1, C32.1, C33.1, C34.1, R18.1, R19.1, R22.1, R26.1, R42.1, R43.1, R45.1, R49.1, R61.1, R62.1, R64.1, R68.1, S1.C, S1.GND1 (G), S1.GND2 (G), S2.C, S2.GND1 (G), S2.GND2 (G), S3.GND1 (G), S3.GND2 (G), S4.GND1 (G), S4.GND2 (G), S5.GND1 (G), S5.GND2 (G), S6.GND1 (G), S6.GND2 (G), S7.GND1 (G), S7.GND2 (G), S8.GND1 (G), S8.GND2 (G), S9.3; also elsewhere on the board
unnamed: D9.1 (A), S11.1
unnamed: D1.1 (A), S1.E (2)
unnamed: D2.1 (A), S2.E (2)
unnamed: R66.1, R74.1, S5.A
unnamed: R61.2, R63.1, R71.1, S5.B
unnamed: D4.1 (A), S3.E (2)
unnamed: D5.1 (A), S4.E (2)
unnamed: D7.1 (A), S5.E (2)
unnamed: D8.1 (A), S6.E (2)
unnamed: D6.1 (A), S7.E (2)
unnamed: D3.1 (A), S8.E (2)
unnamed: R64.2, R65.2, S5.C
unnamed: R6.1, R11.1, S1.A
unnamed: R5.1, R9.1, S1.B
unnamed: R70.1, R75.1, S6.A
unnamed: R62.2, R67.1, R72.1, S6.B
unnamed: R68.2, R69.2, S6.C
unnamed: R8.1, R12.1, S2.A
unnamed: R7.1, R10.1, S2.B
unnamed: R47.1, R57.1, S7.A
unnamed: R42.2, R44.1, R52.1, S7.B
unnamed: R45.2, R46.2, S7.C
unnamed: R24.1, R31.1, S3.A
unnamed: R18.2, R21.1, R29.1, S3.B
unnamed: R22.2, R23.2, S3.C
unnamed: R28.1, R32.1, S8.A
unnamed: R19.2, R25.1, R30.1, S8.B
unnamed: R26.2, R27.2, S8.C
unnamed: R51.1, R58.1, S4.A
unnamed: R43.2, R48.1, R53.1, S4.B
unnamed: R49.2, R50.2, S4.C
ROW0: S1.D (1), S2.D (1), S3.D (1); also elsewhere on the board
ROW1: S4.D (1), S5.D (1), S6.D (1); also elsewhere on the board
ROW2: S7.D (1), S8.D (1), S11.3; also elsewhere on the board
S1A: C6.2, R5.2; also elsewhere on the board
S1B: C9.2, R6.2; also elsewhere on the board
S2A: C7.2, R7.2; also elsewhere on the board
S2B: C10.2, R8.2; also elsewhere on the board
S3A: C12.2, R21.2; also elsewhere on the board
S3B: C13.2, R23.1, R24.2; also elsewhere on the board
S4A: C26.2, R48.2; also elsewhere on the board
S4B: C27.2, R50.1, R51.2; also elsewhere on the board
S5A: C31.2, R63.2; also elsewhere on the board
S5B: C32.2, R65.1, R66.2; also elsewhere on the board
S6A: C33.2, R67.2; also elsewhere on the board
S6B: C34.2, R69.1, R70.2; also elsewhere on the board
S7A: C24.2, R44.2; also elsewhere on the board
S7B: C25.2, R46.1, R47.2; also elsewhere on the board
S8A: C14.2, R25.2; also elsewhere on the board
S8B: C15.2, R27.1, R28.2; also elsewhere on the board
S9/ISP: S9.1 (2); also elsewhere on the board

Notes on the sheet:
Switches
Rotary encoders
LCD, buzzer
ISP/Mode

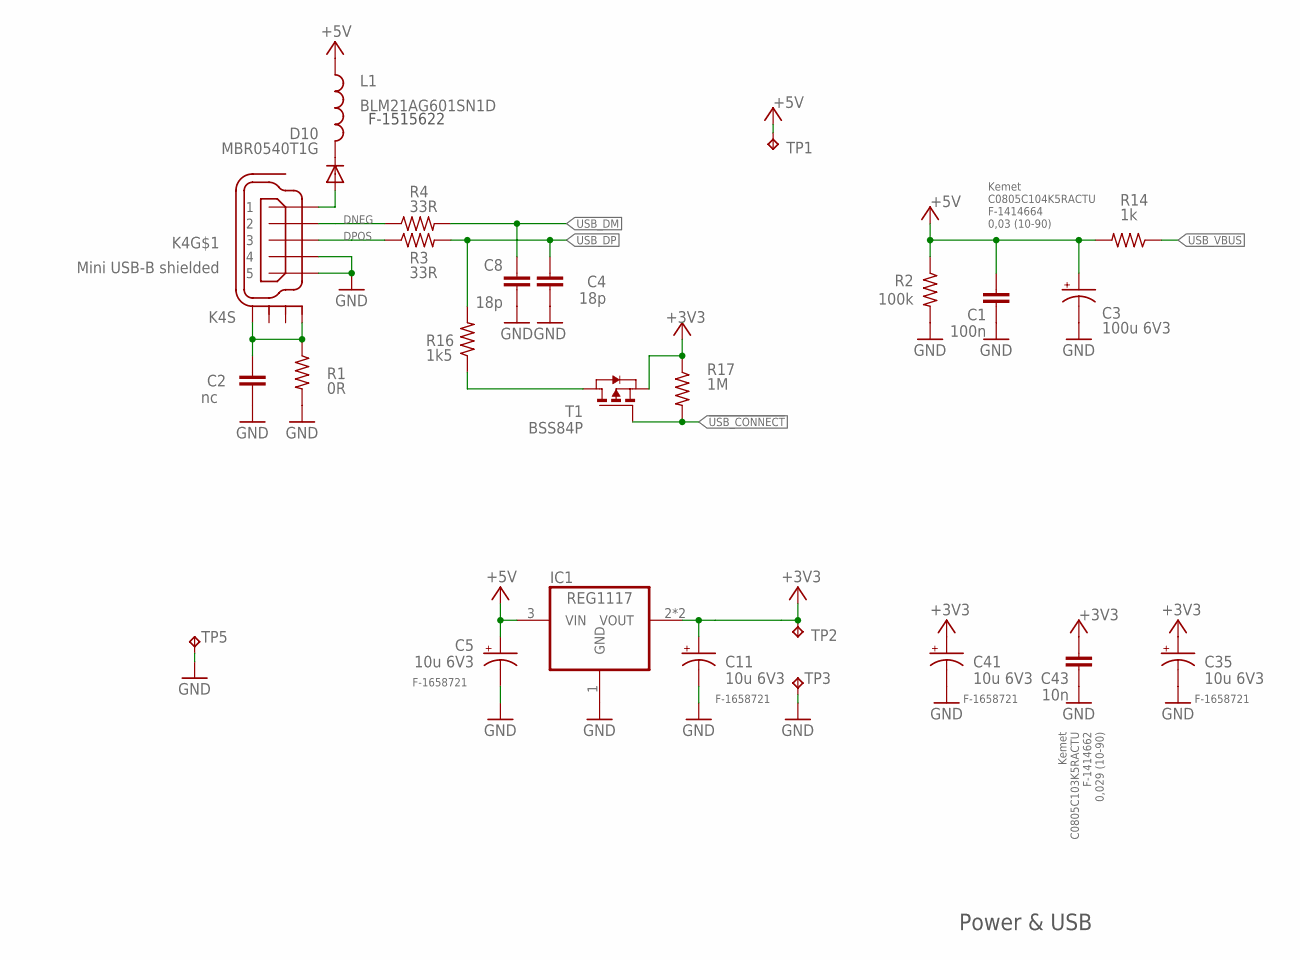
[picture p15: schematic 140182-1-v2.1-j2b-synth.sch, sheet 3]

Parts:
C1: 100n; C0805K; FARNELL F-1414664
C2: nc; C0805K
C3: 100u 6V3; B/3528-21R; FARNELL F-1754068
C4, C8: 18p; C0805K
C5, C11, C35, C41: 10u 6V3; SMC_Z; FARNELL F-1658721
C43: 10n; C0805K; FARNELL F-1414662
D10: MBR0540T1G; SOD123
IC1: REG1117; SOT223
K4: Mini USB-B shielded; USB-MINI-B; FARNELL F-1125348
L1: BLM21AG601SN1D; 0805
R1: 0R; R0805; FARNELL F-1576156
R2: 100k; R0805; FARNELL F-9333738
R3, R4: 33R; R0805
R14: 1k; R0805; FARNELL F-9333711
R16: 1k5; R0805
R17: 1M; R0805
T1: BSS84P; SOT-23
TP1, TP2, TP3, TP5: TPPAD1-13; P1-13

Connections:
!USB_CONNECT: R17.2, T1.3 (G); also elsewhere on the board
+3V3: C11.+, C35.+, C41.+, C43.2, IC1.2 (VOUT), IC1.4 (VOUT), R17.1, T1.2 (S), TP2.TP; also elsewhere on the board
+5V: C1.2, C3.+, C5.+, IC1.3 (VIN), L1.2, R2.1, R14.2, TP1.TP; also elsewhere on the board
DNEG: K4.2, R4.1
DPOS: K4.3, R3.1
GND: C1.1, C2.2, C3.-, C4.2, C5.-, C8.2, C11.-, C35.-, C41.-, C43.1, IC1.1 (GND), K4.4, K4.5, R1.2, R2.2, TP3.TP, TP5.TP; also elsewhere on the board
unnamed: D10.C, L1.1
unnamed: C2.1, K4.M1 (S1), K4.M4 (S4), R1.1
unnamed: D10.A, K4.1
unnamed: R16.1, T1.1 (D)
USB_DM: C8.1, R4.2; also elsewhere on the board
USB_DP: C4.1, R3.2, R16.2; also elsewhere on the board
USB_VBUS: R14.1; also elsewhere on the board

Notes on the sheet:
Power & USB
F-1515622

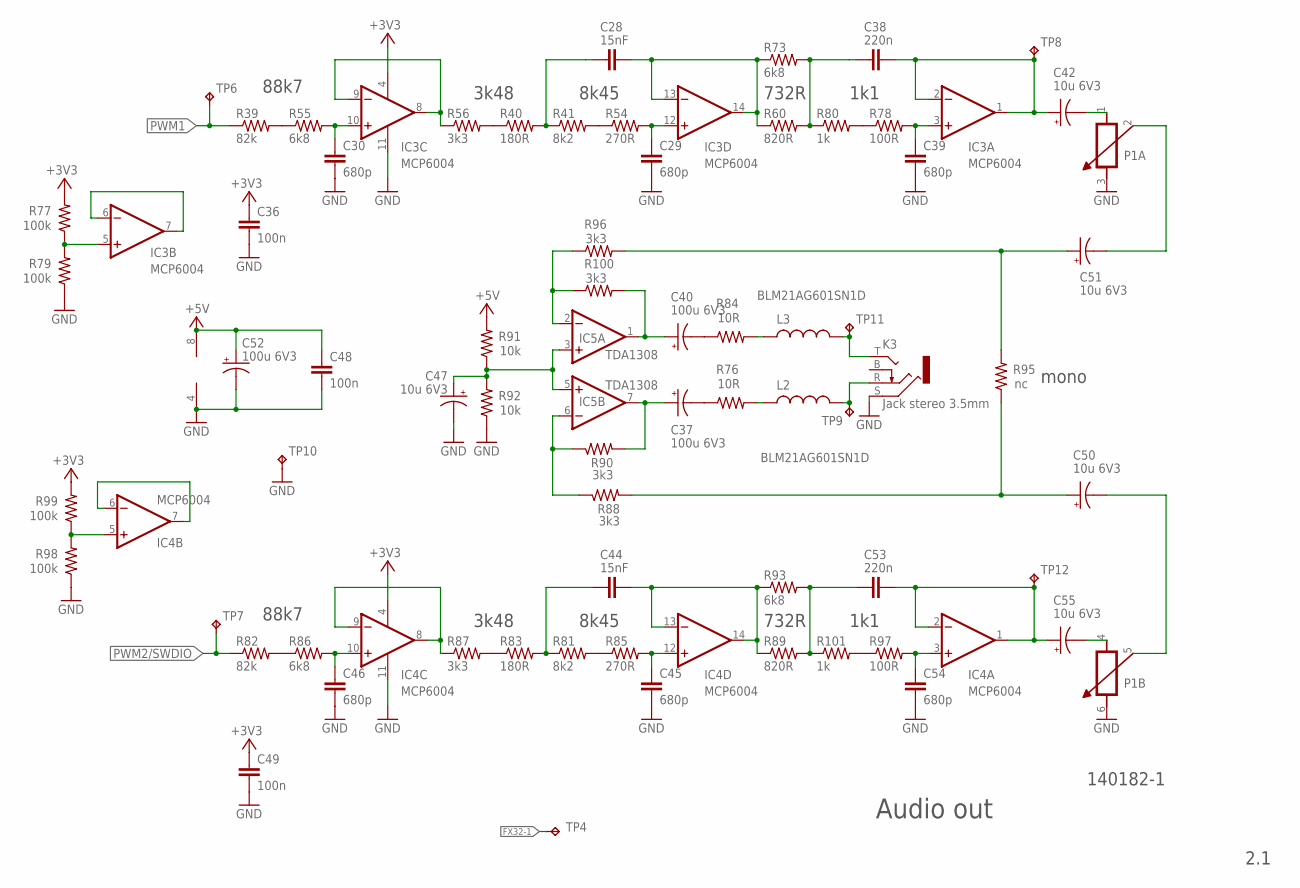
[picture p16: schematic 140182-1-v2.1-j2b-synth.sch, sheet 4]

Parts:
C28, C44: 15nF; C0805K
C29, C30, C39, C45, C46, C54: 680p; C0805K
C36, C48, C49: 100n; C0805K
C37, C40, C52: 100u 6V3; B/3528-21R
C38, C53: 220n; C0805K
C42, C47, C50, C51, C55: 10u 6V3; SMC_Z; FARNELL F-1658721
IC3, IC4: MCP6004; SO14
IC5: TDA1308; SO08
K3: Jack stereo 3.5mm; EPP-JACK-35
L2, L3: BLM21AG601SN1D; 0805
P1: POT-BOURNS-PDT90; POT-BOURNS-PTD90-2-WAY
R39, R82: 82k; R0805
R40, R83: 180R; R0805
R41, R81: 8k2; R0805
R54, R85: 270R; R0805
R55, R73, R86, R93: 6k8; R0805
R56, R87: 3k3; R0805
R60, R89: 820R; R0805
R76, R84: 10R; R0805; FARNELL F-9333711
R77, R79, R98, R99: 100k; R0805
R78, R97: 100R; R0805
R80, R101: 1k; R0805
R88, R90, R96, R100: 3k3; R0805; FARNELL F-9333711
R91, R92: 10k; R0805; FARNELL F-9333711
R95: nc; R0805; FARNELL F-9333711
TP4, TP6, TP7, TP8, TP9, TP10, TP11, TP12: TPPAD1-13; P1-13

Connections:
+3V3: C36.1, C49.1, IC3.4 (V+), IC4.4 (V+), R77.2, R99.2; also elsewhere on the board
+5V: C48.1, C52.+, IC5.8 (V+), R91.2; also elsewhere on the board
CH1: C38.2, C42.+, IC3.1 (OUT), IC3.2 (-IN), TP8.TP
CH2: C53.2, C55.+, IC4.1 (OUT), IC4.2 (-IN), TP12.TP
FX32-1: TP4.TP; also elsewhere on the board
GND: C29.2, C30.2, C36.2, C39.2, C45.2, C46.2, C47.-, C48.2, C49.2, C52.-, C54.2, IC3.11 (V-), IC4.11 (V-), IC5.4 (V-), K3.S, P1.3 (B), P1.6 (B), R79.1, R92.1, R98.1, TP10.TP; also elsewhere on the board
HPIN1: C51.+, R95.2, R96.2
HPIN2: C50.+, R88.2, R95.1
unnamed: IC5.2 (-IN), R96.1, R100.1
unnamed: C40.+, IC5.1 (OUT), R100.2
unnamed: L3.2, R84.2
unnamed: L2.2, R76.2
unnamed: C40.-, R84.1
unnamed: C37.-, R76.1
unnamed: C46.1, IC4.10 (+IN), R86.2
unnamed: IC5.6 (-IN), R88.1, R90.1
unnamed: C37.+, IC5.7 (OUT), R90.2
unnamed: IC4.8 (OUT), IC4.9 (-IN), R87.1
unnamed: C45.1, IC4.12 (+IN), R85.2
unnamed: C44.2, IC4.13 (-IN), IC4.14 (OUT), R89.1, R93.1
unnamed: C54.1, IC4.3 (+IN), R97.2
unnamed: R82.2, R86.1
unnamed: R83.1, R87.2
unnamed: R81.2, R85.1
unnamed: R97.1, R101.2
unnamed: C44.1, R81.1, R83.2
unnamed: C53.1, R89.2, R93.2, R101.1
unnamed: C55.-, P1.4 (A)
unnamed: C42.-, P1.1 (A)
unnamed: C47.+, IC5.3 (+IN), IC5.5 (+IN), R91.1, R92.2
unnamed: IC4.5 (+IN), R98.2, R99.1
unnamed: IC4.6 (-IN), IC4.7 (OUT)
unnamed: C30.1, IC3.10 (+IN), R55.2
unnamed: IC3.8 (OUT), IC3.9 (-IN), R56.1
unnamed: C29.1, IC3.12 (+IN), R54.2
unnamed: C28.2, IC3.13 (-IN), IC3.14 (OUT), R60.1, R73.1
unnamed: C39.1, IC3.3 (+IN), R78.2
unnamed: R39.2, R55.1
unnamed: R40.1, R56.2
unnamed: R41.2, R54.1
unnamed: R78.1, R80.2
unnamed: C28.1, R40.2, R41.1
unnamed: C38.1, R60.2, R73.2, R80.1
unnamed: IC3.5 (+IN), R77.1, R79.2
unnamed: IC3.6 (-IN), IC3.7 (OUT)
OUT1: K3.T, L3.1, TP11.TP
OUT2: K3.R, L2.1, TP9.TP
P1AW: C51.-, P1.2 (WIPER)
P1BW: C50.-, P1.5 (WIPER)
PWM1: R39.1, TP6.TP; also elsewhere on the board
PWM2/SWDIO: R82.1, TP7.TP; also elsewhere on the board

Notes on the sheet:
Audio out
88k7
3k48
8k45
732R
1k1
mono

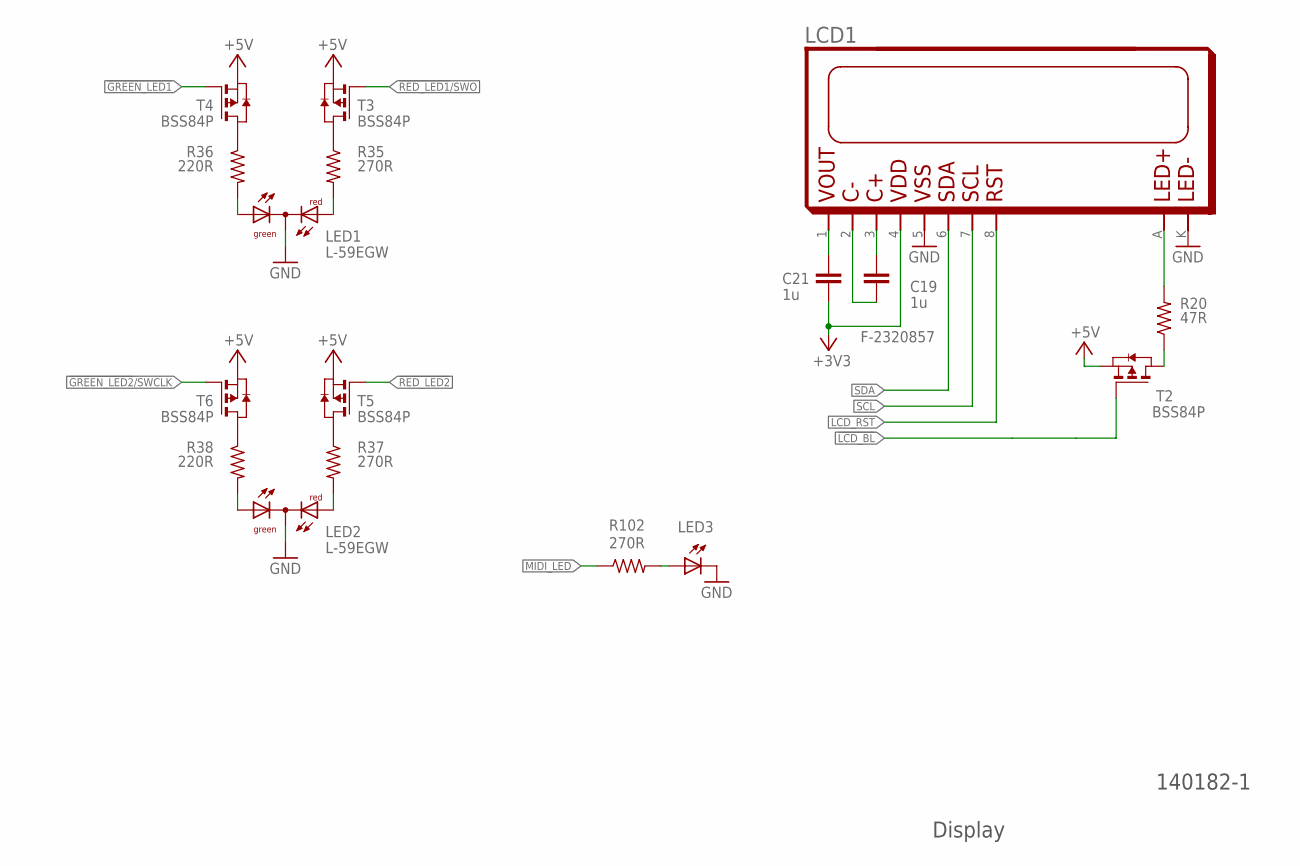
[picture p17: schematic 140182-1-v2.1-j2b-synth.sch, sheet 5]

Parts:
C19: 1u; C0805K; FARNELL F-2320857
C21: 1u; C0805K
LCD1: LCD-I2C-MIDAS; LCD-MIDAS-I2C
LED1, LED2: L-59EGW; DUOLED-C-5MM; FARNELL 2001770
LED3: LED3MM
R20: 47R; R1206; FARNELL F-1576615
R35, R37, R102: 270R; R0805; FARNELL F-1576615
R36, R38: 220R; R0805; FARNELL F-1576615
T2, T3, T4, T5, T6: BSS84P; SOT-23

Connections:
!GREEN_LED1!: T4.3 (G); also elsewhere on the board
!GREEN_LED2!/SWCLK: T6.3 (G); also elsewhere on the board
!LCD_BL: T2.3 (G); also elsewhere on the board
!RED_LED1!/SWO: T3.3 (G); also elsewhere on the board
!RED_LED2: T5.3 (G); also elsewhere on the board
+3V3: C21.2, LCD1.4; also elsewhere on the board
+5V: T2.2 (S), T3.2 (S), T4.2 (S), T5.2 (S), T6.2 (S); also elsewhere on the board
GND: LCD1.5, LCD1.K, LED1.C, LED2.C, LED3.K (C); also elsewhere on the board
LCD_RST: LCD1.8; also elsewhere on the board
MIDI_LED: R102.1; also elsewhere on the board
unnamed: LED1.AX (AG), R36.2
unnamed: R36.1, T4.1 (D)
unnamed: C21.1, LCD1.1
unnamed: LED1.AR, R35.2
unnamed: C19.1, LCD1.3
unnamed: C19.2, LCD1.2
unnamed: R35.1, T3.1 (D)
unnamed: LED2.AX (AG), R38.2
unnamed: R38.1, T6.1 (D)
unnamed: LED3.A, R102.2
unnamed: LED2.AR, R37.2
unnamed: R37.1, T5.1 (D)
unnamed: R20.1, T2.1 (D)
unnamed: LCD1.A, R20.2
SCL: LCD1.7; also elsewhere on the board
SDA: LCD1.6; also elsewhere on the board

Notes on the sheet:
Display

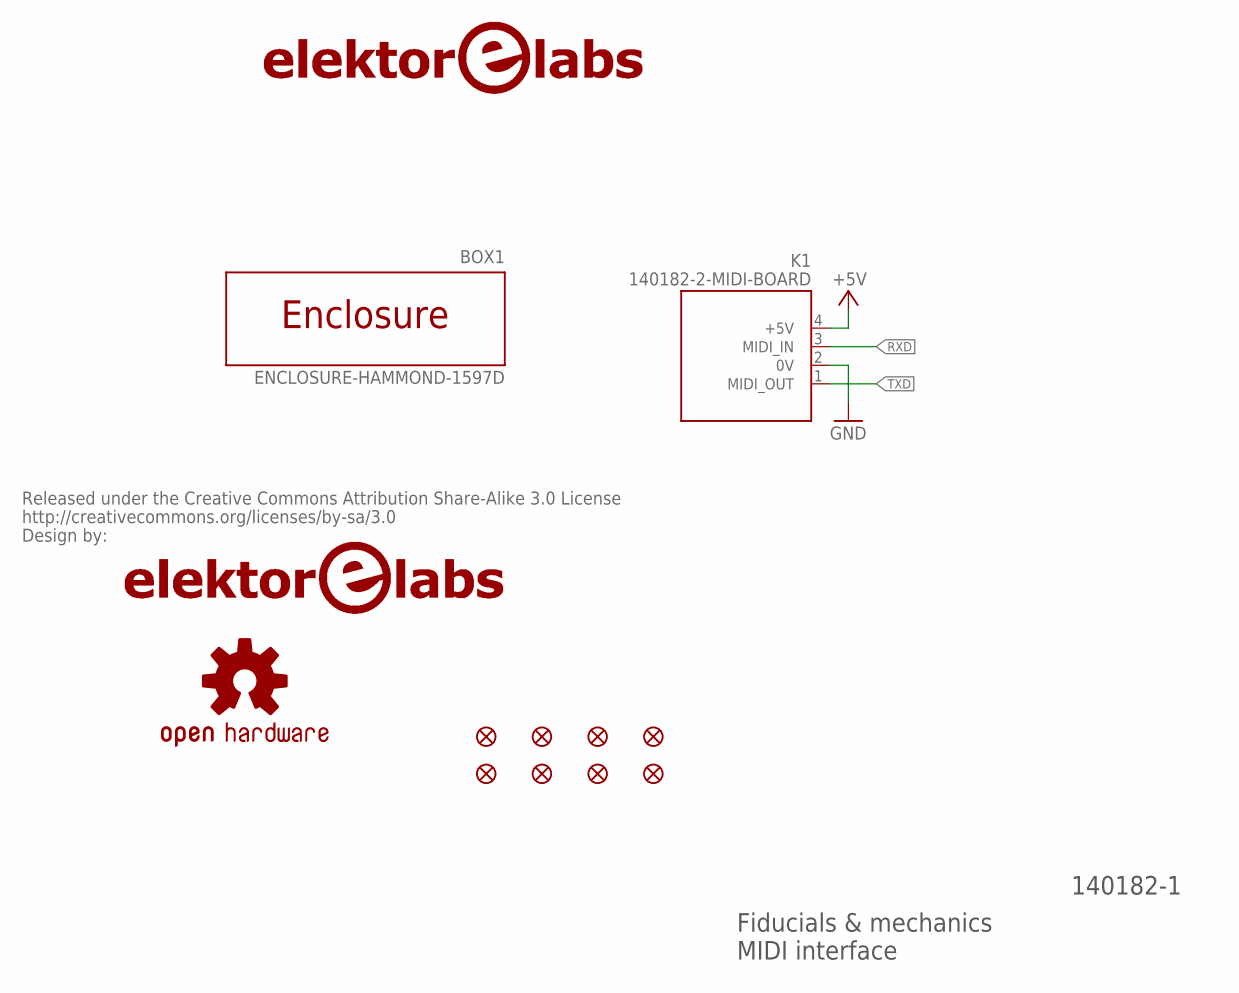
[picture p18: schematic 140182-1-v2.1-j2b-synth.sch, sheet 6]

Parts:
BOX1: ENCLOSURE-HAMMOND-1597D; HAMMOND-1597DGY
FID1, FID2, FID3, FID4, FID5, FID6, FID7, FID8: FIDUCIAL1.5X3; FIDUCIAL-1.5X3
K1: 140182-2-MIDI-BOARD; 140182-2-MIDI_BOARD
LOGO1, LOGO2: LOGO-ELEKTOR-LABS-42MM; EPP-LOGO-ELEKTOR-LABS-42MM
U$1: OSHW-LOGOL; OSHW-LOGO-L
U$2: CREATIVE_COMMONS

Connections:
+5V: K1.4 (+5V); also elsewhere on the board
GND: K1.2 (0V); also elsewhere on the board
RXD: K1.3 (MIDI_IN); also elsewhere on the board
TXD: K1.1 (MIDI_OUT); also elsewhere on the board

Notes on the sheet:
Fiducials & mechanics
MIDI interface

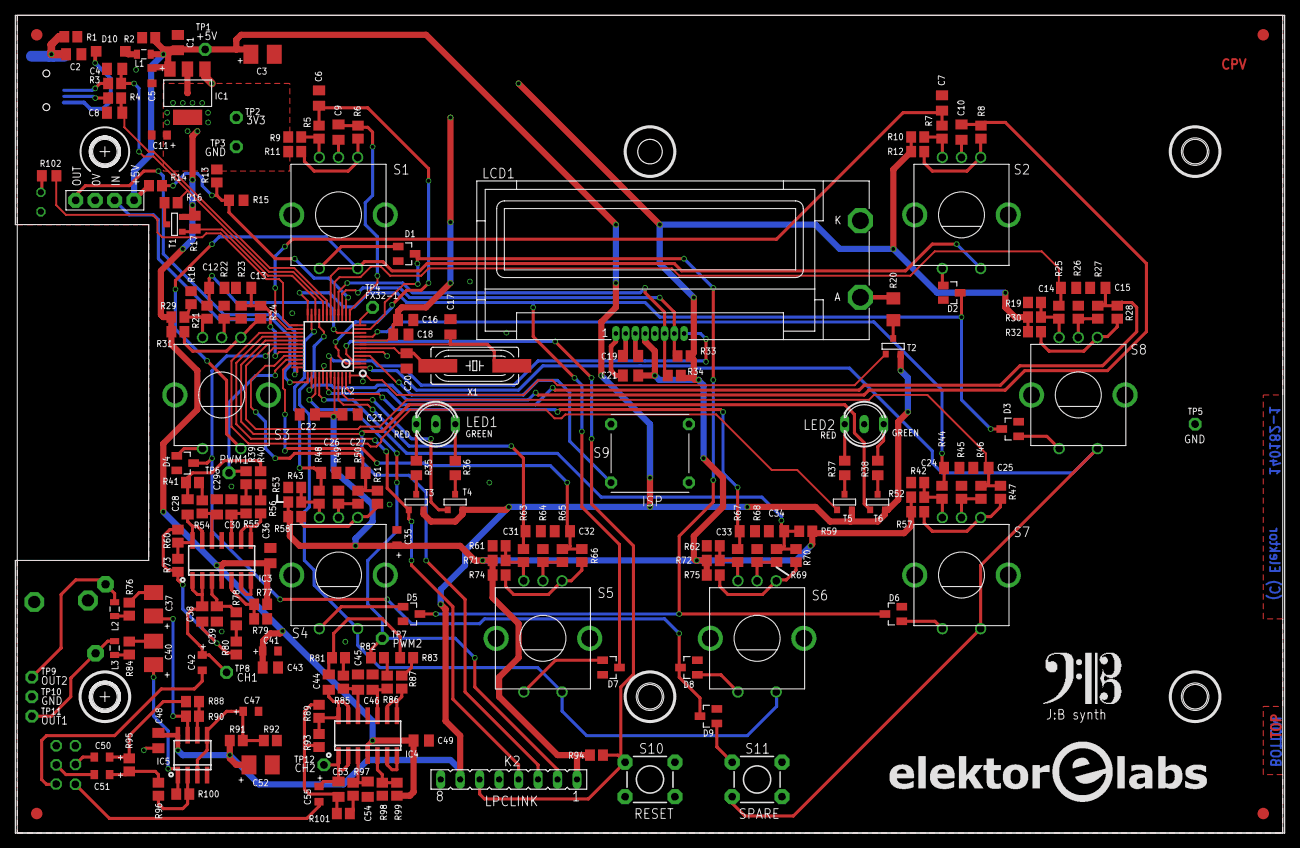
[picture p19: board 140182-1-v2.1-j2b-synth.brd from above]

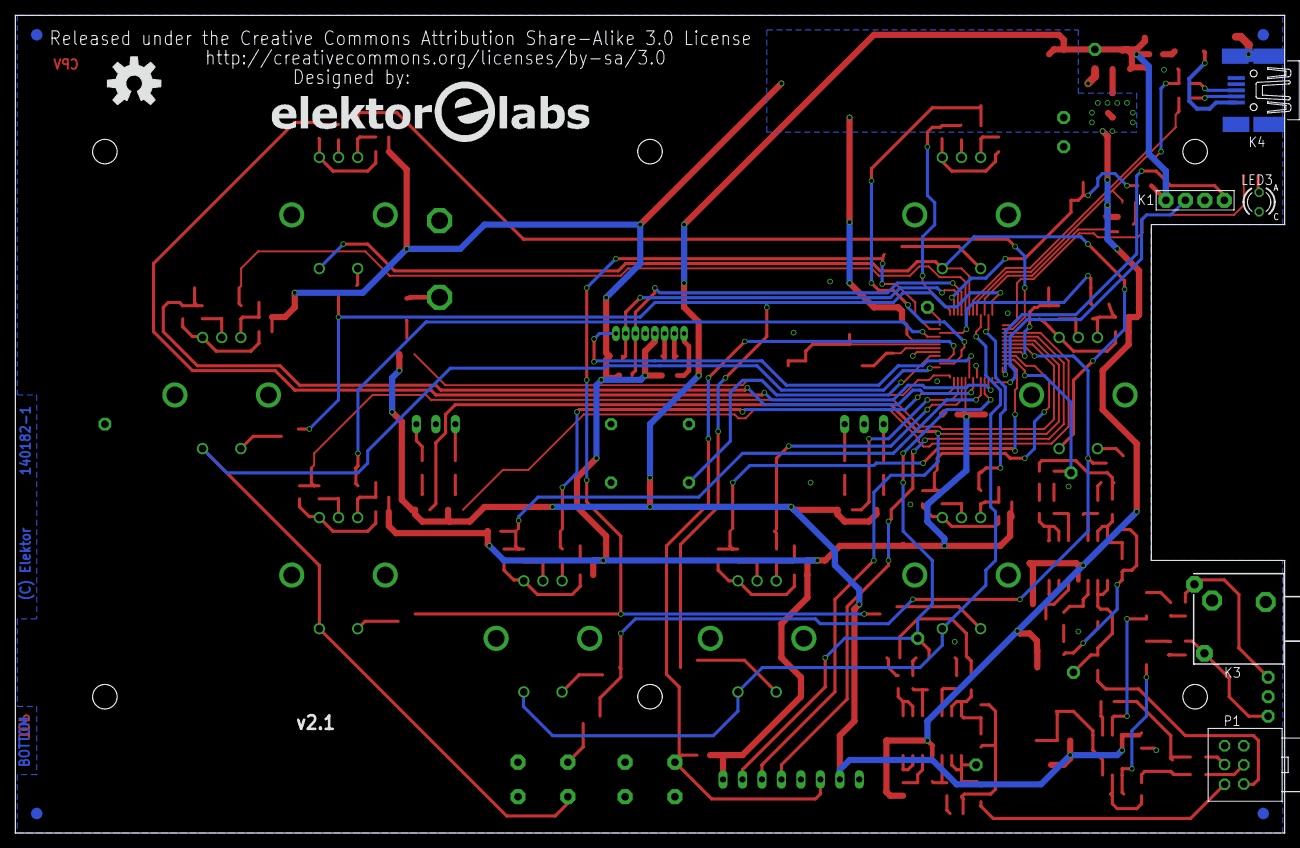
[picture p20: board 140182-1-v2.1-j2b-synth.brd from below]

Board: 2 copper layers, 165.6 x 106.7 mm, 227 parts (11 on the bottom side), 143 nets.

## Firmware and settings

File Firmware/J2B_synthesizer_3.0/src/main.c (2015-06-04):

/*
 * @brief J2B Synthesizer
 *
 * @note
 * Copyright (C) Elektor, 2014
 * All rights reserved.
 *
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
 * @par
 * Permission to use, copy, modify, and distribute this software and its
 * documentation is hereby granted, under Elektor's and its licensor's
 * relevant copyrights in the software, without fee.  This copyright, 
 * permission, and disclaimer notice must appear in all copies of this code.
 */

#include "chip.h"
#include "board.h"
#include "systick.h"
#include "pwm_timer.h"
#include "atmegatron.h"
#include "lcd.h"


#define J2B_PROCESSING  (1)


pwm_timer_t sample_rate_clock;
pwm_timer_t audio_out_clock;
#define AUDIO_OUT_CHANNEL_1  (0)
#define AUDIO_OUT_CHANNEL_2  (2)
#define AUDIO_OUT_FREQUENCY_REGISTER  (PWM_TIMER_FREQUENCY_REGISTER)
#define SAMPLE_RATE_OUT_CHANNEL  (3)
#define SAMPLE_RATE_FREQUENCY_REGISTER  (0)

volatile uint32_t pwm_update = 256;
volatile uint32_t pwm_update_ch2 = 256;
boolean mono = false;

// Audio out ISR
void TIMER32_1_IRQHandler(void)
{
	if (Chip_TIMER_MatchPending(LPC_TIMER32_1,AUDIO_OUT_FREQUENCY_REGISTER))
	{
		Chip_TIMER_ClearMatch(LPC_TIMER32_1,AUDIO_OUT_FREQUENCY_REGISTER);

#if PRODUCT==DELAYERTRON
	{
		// This code is supposed to run at the PWM frequency (31.373 kHz or 16MHz/510 on Delayertron).
		uint16_t mult;
		uint16_t bs;
		uint16_t master_waveindex;
		int32_t master_out;

		mult = MIDI_mult[master_curnote];
		bs = MIDI_bs[master_curnote];
		master_waveindex = (master_index * mult >> bs) % WAVE_LEN;

		if (master_waveindex < master_lastwaveindex)
		{
			master_aenvlevel = Aenv_Get_Level();
			master_curnote = Pitch_Get_FreqCalc(); // get note
			master_index = 0;
		}
		master_lastwaveindex = master_waveindex;

#if J2B_PROCESSING==1
		master_out = wave_store[master_curbank][master_curtable][master_waveindex];
		// Multiply sample by current amp env level (0-255) and divide by 256
		master_out = master_out * master_aenvlevel >> 8;
		// 100% dry mix is actually set here
		master_dry = (sample_t) master_out;
		master_wet = delay_buffer[delay_readpos]; // CPV
		if (master_dm==8)
		{
			// 100% wet mix
			master_out = master_wet;
		}
		else if (master_wm<8)
		{
			// wet/dry mix
			master_out = (master_dry >> master_dm) + (master_wet >> master_wm);
		}

		// master_clipbs is Delay_(L/G)et_ClipMode, can be 0 or 1.
		master_out = master_out >> master_clipbs;
#elif J2B_PROCESSING==2
		master_dry = (master_aenvlevel*wave_store[master_curbank][master_curtable][master_waveindex]) >> (8-master_wm);
		master_wet = delay_buffer[delay_readpos] << master_dm;
		master_out = (master_dry+master_wet) >> (master_wm+master_dm+master_clipbs);
#endif

		if (Filt_Get_Type()>0 && Filt_Get_PostDelay()==false)
		{
			master_out = Filter_Process(master_out);
		}

		if (master_out>127)
		{
			pwm_update = 255;
		}
		else if (master_out<-128)
		{
			pwm_update = 0;
		}
		else
		{
			pwm_update = master_out + 128;
		}
		pwm_update_ch2 = pwm_update;

		master_index++;  //increment position in wavetable
	}
#endif /* PRODUCT */

		Chip_TIMER_SetMatch(LPC_TIMER32_1,AUDIO_OUT_CHANNEL_1,pwm_update);
		Chip_TIMER_SetMatch(LPC_TIMER32_1,AUDIO_OUT_CHANNEL_2,pwm_update_ch2);
	}
}


// Pitch ISR
void TIMER32_0_IRQHandler(void)
{
	if (Chip_TIMER_MatchPending(LPC_TIMER32_0,SAMPLE_RATE_FREQUENCY_REGISTER))
	{
		// Clear interrupt flag.
		Chip_TIMER_ClearMatch(LPC_TIMER32_0,SAMPLE_RATE_FREQUENCY_REGISTER);
		
#if PRODUCT==ATMEGATRON
		// If at end of wavetable, go back to start.
		if (master_index>WAVE_LEN-1)
		{
			master_index = 0;
		}

		// Set sample value.
		// We have 4 bits more resolution than on AVR so multiply by 4.
		// pwm_update is consumed in the Audio Out ISR.
		pwm_update = master_output[master_index] + 128;
		pwm_update_ch2 = pwm_update;

		/* CPV - for later
		if (mono==true) pwm_update_ch2 = master_output[master_index] + 128;
		else pwm_update_ch2 = master_output_ch2[master_index] + 128;*/

		//Chip_TIMER_SetMatch(audio_out_clock.timer,AUDIO_OUT_CHANNEL,master_output[master_index]+128);
		// Increment position in wavetable.
		master_index++;
#endif /* PRODUCT */
		
#if PRODUCT==ATCYCLOTRON
		//sets sample value to current index of current wave
		pwm_update = master_output[master_curwave][master_index] + 128;
		pwm_update_ch2 = pwm_update;

		/* CPV - for later
		 * if (mono==true) pwm_update_ch2 = master_output[master_curwave][master_index] + 128;
		else pwm_update_ch2 = master_output_ch2[master_curwave][master_index] + 128;*/

		master_index++;                                //increment index (position in wavetable)
		if (master_index > WAVE_LEN-1)
		{
			//if at end of wavetable, go back to start
			master_index = 0;
		}
		master_cyclecurinc++;                          //increment current wave increment
		if (master_cyclecurinc >= master_cycleinc)
		{
			//if current wave increment >= wave increment value    ***32 = full wave cycle playback
			master_cyclecurrep++;                          //increment current wave repeat
			if (master_cyclecurrep >= master_cyclerep)
			{
				//if current wave repeart >= wave repeat value       ***1 = single cycle playback
				master_curwave++;                              //increment current wave number
				if (master_curwave >= TOT_WAVES)
				{
					//if current wave number >= 4 then reset current wave
					master_curwave = 0;
				}
				master_cyclecurrep = 0;                        //reset current wave repeat
			}
			master_cyclecurinc = 0;                        //reset current wave increment
		}
#endif /* PRODUCT */

#if PRODUCT==ATMEGADRUM
		master_sum =
			(Wavestore_Get_Sample(master_index[0])>>Seq_Get_Amplitude(0)) +
			(Wavestore_Get_Sample(master_index[1])>>Seq_Get_Amplitude(1)) + 
			(Wavestore_Get_Sample(master_index[2])>>Seq_Get_Amplitude(2)) +
			(Wavestore_Get_Sample(master_index[3])>>Seq_Get_Amplitude(3)) + 
			(Wavestore_Get_Sample(master_index[4])>>Seq_Get_Amplitude(4)) + 
			(Wavestore_Get_Sample(master_index[5])>>Seq_Get_Amplitude(5)) + 
			(Wavestore_Get_Sample(master_index[6])>>Seq_Get_Amplitude(6)) + 
			(Wavestore_Get_Sample(master_index[7])>>Seq_Get_Amplitude(7)) + 
			(Wavestore_Get_Sample(master_index[8])>>Seq_Get_Amplitude(8)) + 
			(Wavestore_Get_Sample(master_index[9])>>Seq_Get_Amplitude(9)) + 
			(Wavestore_Get_Sample(master_index[10])>>Seq_Get_Amplitude(10)) + 
			(Wavestore_Get_Sample(master_index[11])>>Seq_Get_Amplitude(11)) + 
			(Wavestore_Get_Sample(master_index[12])>>Seq_Get_Amplitude(12)) + 
			(Wavestore_Get_Sample(master_index[13])>>Seq_Get_Amplitude(13)) +
			(Wavestore_Get_Sample(master_index[14])>>Seq_Get_Amplitude(14)) + 
			(Wavestore_Get_Sample(master_index[15])>>Seq_Get_Amplitude(15));

		// Scale back to compensate for addition.
		// Why isn't this done in the original Atmegadrum firmware??? (v1.2)
		// The sound quality is already crappy enough like this.
		master_sum >>= 3;

		// Let's do this the other way around for better sound quality.
		// Instead of shifting to the right and losing lots of bits, we now
		// shift to the left and divide afterwards.
		/*master_sum =
			(Wavestore_Get_Sample(master_index[0])<<(7-Seq_Get_Amplitude(0))) +
			(Wavestore_Get_Sample(master_index[1])<<(7-Seq_Get_Amplitude(1))) +
			(Wavestore_Get_Sample(master_index[2])<<(7-Seq_Get_Amplitude(2))) +
			(Wavestore_Get_Sample(master_index[3])<<(7-Seq_Get_Amplitude(3))) +
			(Wavestore_Get_Sample(master_index[4])<<(7-Seq_Get_Amplitude(4))) +
			(Wavestore_Get_Sample(master_index[5])<<(7-Seq_Get_Amplitude(5))) +
			(Wavestore_Get_Sample(master_index[6])<<(7-Seq_Get_Amplitude(6))) +
			(Wavestore_Get_Sample(master_index[7])<<(7-Seq_Get_Amplitude(7))) +
			(Wavestore_Get_Sample(master_index[8])<<(7-Seq_Get_Amplitude(8))) +
			(Wavestore_Get_Sample(master_index[9])<<(7-Seq_Get_Amplitude(9))) +
			(Wavestore_Get_Sample(master_index[10])<<(7-Seq_Get_Amplitude(10))) +
			(Wavestore_Get_Sample(master_index[11])<<(7-Seq_Get_Amplitude(11))) +
			(Wavestore_Get_Sample(master_index[12])<<(7-Seq_Get_Amplitude(12))) +
			(Wavestore_Get_Sample(master_index[13])<<(7-Seq_Get_Amplitude(13))) +
			(Wavestore_Get_Sample(master_index[14])<<(7-Seq_Get_Amplitude(14))) +
			(Wavestore_Get_Sample(master_index[15])<<(7-Seq_Get_Amplitude(15)));

		master_sum >>= 10;*/

		if (master_sum>127)
		{
			master_output=255;
		}
		else if (master_sum<-128)
		{
			master_output=0;
		}
		else
		{
			master_output = master_sum + 128;
		}
		pwm_update = master_output;
		pwm_update_ch2 = master_output;
		
		if (master_index[0]<Wavestore_Get_Start(1)) master_index[0]++; 
		if (master_index[1]<Wavestore_Get_Start(2)) master_index[1]++; 
		if (master_index[2]<Wavestore_Get_Start(3)) master_index[2]++; 
		if (master_index[3]<Wavestore_Get_Start(4)) master_index[3]++; 
		if (master_index[4]<Wavestore_Get_Start(5)) master_index[4]++; 
		if (master_index[5]<Wavestore_Get_Start(6)) master_index[5]++; 
		if (master_index[6]<Wavestore_Get_Start(7)) master_index[6]++; 
		if (master_index[7]<Wavestore_Get_Start(8)) master_index[7]++; 
		if (master_index[8]<Wavestore_Get_Start(9)) master_index[8]++; 
		if (master_index[9]<Wavestore_Get_Start(10)) master_index[9]++; 
		if (master_index[10]<Wavestore_Get_Start(11)) master_index[10]++; 
		if (master_index[11]<Wavestore_Get_Start(12)) master_index[11]++; 
		if (master_index[12]<Wavestore_Get_Start(13)) master_index[12]++; 
		if (master_index[13]<Wavestore_Get_Start(14)) master_index[13]++; 
		if (master_index[14]<Wavestore_Get_Start(15)) master_index[14]++; 
		if (master_index[15]<Wavestore_Get_Start(16)) master_index[15]++; 
#endif /* PRODUCT */

#if PRODUCT==DELAYERTRON
		{
			// This code is supposed to run at the sample rate frequency.
			sample_t rp, msb, lsb;
			int wp;

			if (master_wm==8)
			{
				// 100% wet.
				return;
			}
			if (Delay_Get_Feedback()==0)
			{
#if J2B_PROCESSING==1
				wp = master_dry;
#elif J2B_PROCESSING==2
				wp = master_dry >> master_wm;
#endif
				/*if (Filt_Get_Type()>0 && Filt_Get_PostDelay()==true)
				{
					wp = Filter_Process(wp);
				}
				delay_buffer[delay_writepos] = wp;*/
			}
			else
			{
				rp = delay_buffer[delay_readpos];
				msb = rp >> delay_fbmsb >> master_clipbs;
				if (msb==-1 && delay_fbmsb>0)
				{
					msb = 0;
				}
				lsb = rp >> delay_fblsb >> master_clipbs;
				if (lsb==-1 && delay_fblsb>0)
				{
					lsb = 0;
				}

#if J2B_PROCESSING==1
				wp = (master_dry >> master_clipbs) + msb + lsb;
#elif J2B_PROCESSING==2
				wp = (master_dry >> (master_wm+master_clipbs)) + msb + lsb;
#endif

				/*if (Filt_Get_Type()>0 && Filt_Get_PostDelay()==true)
				{
					wp = Filter_Process(wp);
				}
				if (wp<-128)
				{
					delay_buffer[delay_writepos] = -128;
				}
				else if (wp>127)
				{
					delay_buffer[delay_writepos] = 127;
				}
				else
				{
					delay_buffer[delay_writepos] = (sample_t)wp;
				}*/
			}

			if (Filt_Get_Type()>0 && Filt_Get_PostDelay()==true)
			{
				wp = Filter_Process(wp);
			}
			if (wp<-128) wp = -128;
			else if (wp>127) wp = 127;
			//else if (wp>-2 && wp<2) wp = 0; // CPV
			delay_buffer[delay_writepos] = (sample_t)wp;

			if (delay_writepos > DELAY_SIZE-2)
			{
				//if at end of wavetable, go back to start
				delay_writepos = 0;
			}
			else
			{
				delay_writepos++;
			}
			if (delay_readpos > DELAY_SIZE-2)
			{
				//if at end of wavetable, go back to start
				delay_readpos = 0;
			}
			else
			{
				delay_readpos++;
			}
		}
#endif /* PRODUCT */

		// Set pitch.
		Chip_TIMER_SetMatch(LPC_TIMER32_0,SAMPLE_RATE_FREQUENCY_REGISTER,master_ocr1);
		// Keep duty-cycle of 50%.
		Chip_TIMER_SetMatch(LPC_TIMER32_0,SAMPLE_RATE_OUT_CHANNEL,master_ocr1>>1);
	}
}




void setup(void)
{
	// The hardware setup has been removed from setup and is done before.
	// Here we now only initialize synthesizer stuff.

#if PRODUCT==ATMEGATRON ||PRODUCT==ATCYCLOTRON
	Init_Waves();  // Initialize wavetables.
	//Init_Hardware();  // Initialize input controls.
	LFO_CalcVal();  // Initialize LFO.
	AEnv_CalcVal();  // Initialize amplitude envelope.
	FEnv_CalcVal();  // Initialize filter/pitch envelope.
#endif /* PRODUCT */

#if PRODUCT==ATMEGATRON
	Filt_CalcVals();  // Initialize filter.
#endif /* PRODUCT */

#if PRODUCT==ATMEGADRUM
	Init_Master();
	//Init_Hardware();
#endif /* PRODUCT */

	Init_Hardware();

	if (POLL_MIDI==1)
	{
		// Open MIDI port (standard serial port)
		MIDI_Init();
	}
	else
	{
		// Open the port for debugging.
		Serial.begin(9600);
	}

#if PRODUCT==ATMEGATRON ||PRODUCT==ATCYCLOTRON || PRODUCT==DELAYERTRON
	Memory_Vanilla();  //load the Vanilla patch
#endif /* PRODUCT */

	Hardware_LED_StartFlash(0,5);    //flash to say "I'm ready!"
}


void loop_priority_low(void)
{
	static uint32_t t_prev = 0;
	uint32_t t;

	if (POLL_MIDI==1)
	{
		// Poll the MIDI input.
		MIDI_Poll();
	}
	if (POLL_HARD==1)
	{
		t = systick_counter;
		if (t>=t_prev+10)
		{
			// Limit hardware polling to 100 Hz.
			t_prev = t;
			// Poll the hardware (potentiometers, rotary encoders and buttons).
			Hardware_Poll();
		}
	}

#if PRODUCT==ATMEGATRON || PRODUCT==ATCYCLOTRON
	#ifdef POLL_TEST
		{
			if (master_tick>=Testmode_Get_NextTick())
			{
				// If test mode is being used, trigger next test note if it's time to.
				Testmode_ProcessNext();
			}
		}
	#endif
#endif

#if PRODUCT==ATMEGATRON ||PRODUCT==ATCYCLOTRON || PRODUCT==DELAYERTRON
	// Poll the arpeggiator and see if it's time for a note (if it's on).
	Arp_Poll();
#endif

	display_draw(false);
	keyboard_scan_matrix();
}


void loop_priority_high(void)
{
	// Update master_tick.
	//master_tick = systick_counter;
	master_tickspassed = systick_counter - master_tick;
	master_tick += master_tickspassed;

#if PRODUCT==ATMEGADRUM
	Seq_Process();
#endif

	LFO_CalcVal();  //calculate the current output of the LFO
	
#if PRODUCT==ATMEGATRON || PRODUCT==ATCYCLOTRON || PRODUCT==DELAYERTRON
	AEnv_CalcVal();  //calculate the current output of the amplitude envelope
	FEnv_CalcVal();  //calculate the current output of the filter/pitch envelope
#endif
#if PRODUCT==ATMEGATRON
	Filt_CalcVals();  //calculate the variables used by the filter
#endif
#if PRODUCT==ATCYCLOTRON
	Cycle_CalcVals();
#endif
#if PRODUCT==DELAYERTRON
	Filt_CalcFc();  //calculate the variables used by the filter
	Delay_CalcSF();
#endif

	Pitch_Process();  //calculate the current pitch

#if PRODUCT!=DELAYERTRON
	Master_Let_SampleFreq();  //set interrupt freq based on above calculation
#endif
	
#if PRODUCT==ATMEGATRON || PRODUCT==ATCYCLOTRON
	// If a key is down (actually is amplitude envelope idle):
	if (Aenv_Get_State()>0)
	{
		// Process the wavetable (filter/envelope/fx etc...).
		Wave_Process();
		Flange_Process_Channel2();
	}
	// Otherwise clear the wavetable.  This is to stop.
	else
	{
		Wave_Clear();
		Flange_ClearBuffer();
	}
#endif
}


/*void loop(void)
{
	if (POLL_MIDI==1)
	{
		// Poll the MIDI input.
		Chip_GPIO_WritePortBit(LPC_GPIO_PORT,0,10,true);
		MIDI_Poll();
		Chip_GPIO_WritePortBit(LPC_GPIO_PORT,0,10,false);
	}
	if (POLL_HARD==1)
	{
		// Poll the hardware (potentiometers, rotary encoders and buttons).
		Hardware_Poll();
	}

	// Update master_tick.
	master_tick = systick_counter;

	if (POLL_TEST==1)
	{
		if (master_tick>=Testmode_Get_NextTick())
		{
			// If test mode is being used, trigger next test note if it's time to.
			Testmode_ProcessNext();
		}
	}
	Arp_Poll();                                       //poll the arpeggiator and see if it's time for a note (if it's on)
	LFO_CalcVal();                                    //calculate the current output of the LFO
	AEnv_CalcVal();                                   //calculate the current output of the amplitude envelope
	FEnv_CalcVal();                                   //calculate the current output of the filter/pitch envelope
	Filt_CalcVals();                                  //calculate the variables used by the filter
	Pitch_Process();                                  //calculate the current pitch
	Master_Let_SampleFreq();                          //set interrupt freq based on above calculation
	// If a key is down (actually is amplitude envelope idle):
	if (Aenv_Get_State()>0)
	{
		// Process the wavetable (filter/envelope/fx etc...).
		Wave_Process();
	}
	// Otherwise clear the wavetable.  This is to stop.
	else
	{
		Wave_Clear();
		Flange_ClearBuffer();
	}
}*/


int main(void)
{
	// Generic initialization.
	// Before we get here the startup routine has already called SystemInit,
	// which resides in the file sysinit.c
	SystemCoreClockUpdate();
	Board_Init();
	SysTick_Config(SystemCoreClock/SYSTICK_RATE_HZ);

	// Setup LCD, pushbuttons and rotary encoders.
	keyboard_init();
	display_init();

	// Setup PWM timer for audio output.
	// Use default frequency register (MR3).
	// Audio timer is LPC_TIMER32_1, i.e. CT32B1
	// MAT10 (PIO0_13) is PWM1.
	// MAT11 (PIO0_14) is shared with S5B.
	// MAT12 (PIO0_15) is shared with green LED1.
	// MAT13 (PIO0_16) is shared with S6B.
	audio_out_clock = pwm_timers[AUDIO_OUT_TIMER];
	audio_out_clock.frequency_register = AUDIO_OUT_FREQUENCY_REGISTER;
#if PRODUCT==DELAYERTRON
	// Atdelayertron needs much lower PWM frequency because it does a lot
	// of stuff in the PWM ISR.
	PwmTimer_Init(&audio_out_clock,281250/4);
#else
	PwmTimer_Init(&audio_out_clock,281250/2);
#endif
	// Setup channel 0 for PWM output on pin 34 (PIO0_13).
	PwmTimer_InitChannel(&audio_out_clock,AUDIO_OUT_CHANNEL_1,500); // Duty-cycle x10 for more precision.
	PwmTimer_InitChannel(&audio_out_clock,AUDIO_OUT_CHANNEL_2,500); // Duty-cycle x10 for more precision.
	PwmTimer_Start(&audio_out_clock);
	PwmTimer_EnableInterrupt(&audio_out_clock,AUDIO_OUT_FREQUENCY_REGISTER);
	NVIC_SetPriority(TIMER_32_1_IRQn,0);

	// Setup PWM timer for pitch/sample rate.
	// Sample rate timer is LPC_TIMER32_0, i.e. CT32B0
	// MAT00 (PIO0_18) is PWM2.
	// MAT01 (PIO0_19) is shared with S6A.
	// MAT02 (PIO0_1) is shared with the ISP enable pin / S9.
	// MAT03 (PIO1_27) is FX32.
	sample_rate_clock = pwm_timers[SAMPLE_RATE_TIMER];
	sample_rate_clock.frequency_register = SAMPLE_RATE_FREQUENCY_REGISTER;
	// This frequency setting has no effect because master_ocr1 controls the frequency.
	PwmTimer_Init(&sample_rate_clock,440*32);
	// Setup channel 0 for PWM output on pin 12 (PIO1_27).
	PwmTimer_InitChannel(&sample_rate_clock,SAMPLE_RATE_OUT_CHANNEL,500); // Duty-cycle x10 for more precision.
	PwmTimer_Start(&sample_rate_clock);
	PwmTimer_EnableInterrupt(&sample_rate_clock,SAMPLE_RATE_FREQUENCY_REGISTER);
	NVIC_SetPriority(TIMER_32_0_IRQn,1);

	// Initialize random number generator (seems to be missing in original code).
	randomSeed(0); // TODO: find a better seed.

	// Call the Arduino setup function.
	setup();

	// LEDs toggle in interrupt handlers.
	//uint32_t seconds_counter_prev = seconds_counter;

	while (1)
	{
		// Use pushbutton S11 ("Spare") to quickly enter ISP mode.
		/*if (keyboard_get_pushbutton(BOARD_KEYBOARD_S22)==key_pressed)
		{
			__disable_irq();
			// How can we invoke USB ISP mode from software?
			// This call invokes serial ISP.
			Chip_FLASH_ReInvokeISP();
		}*/

		if (keyboard_get_pushbutton_changed(BOARD_KEYBOARD_S22)==true)
		{
			if (keyboard_get_pushbutton(BOARD_KEYBOARD_S22,true)==key_pressed)
			{
				mono = !mono;
			}
		}

		loop_priority_low();
		// The idea was to call loop_priority_high from the systick ISR to
		// fix the sample calculation rate to a stable known value. This
		// was OK on the LPC1343, but execution is too long on the LPC1347?
		// The assembly code is identical for both cases.
		loop_priority_high();

		// Do we need this?
		__WFI();
	}

	return 0;
}

/**
 * @}
 */

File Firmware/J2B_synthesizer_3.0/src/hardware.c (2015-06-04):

#include "atmegatron.h"
#include "lcd.h"


//const uint16_t bg_select_store[16] = {1,2,4,8,16,32,64,128,256,512,1024,2048,4096,8192,16384,32768};              //values used to light single led of led array
//const uint16_t bg_fill_store[16] = {1,3,7,15,31,63,127,255,511,1023,2047,4095,8191,16383,32767,65535};            //values used to fill leds between 0-x of led array
const uint16_t envADR_store[16] = {0,8,23,48,88,151,245,381,574,845,1217,1722,2399,3297,4476,6013};               //times used for attack, decay and release of envelopes
const uchar envS_store[16] = {0,17,34,51,68,85,102,119,136,153,170,187,204,221,238,255};                          //levels used for sustain of envelope1 (unipolar for amplitude)
const signed char fenvS_store[16] = {0,8,17,25,34,42,51,59,68,76,85,93,102,110,119,127};                                 //levels used for sustain of envelope2 (bipolar for filter)
const uint16_t speed_store[16] = {32767,16383,8191,6143,5460,4095,3071,2730,2047,1535,1023,767,511,383,255,127}; //values used for speeds of LFO and arpeggiator
const uint16_t porta_store[16] = {0,5,14,27,46,77,123,195,306,477,740,1145,1768,2728,4207,6484};                  //values for portamento speeds

//lets and gets (not all letable or getable at pres)
#if PRODUCT==ATMEGADRUM

#define LOCKOUT 1000        //time between ctrl stop moving and locking it out
#define FLASHLONGTIME 300
#define FLASHSHORTTIME 150
#define MAXVAL 15
byte hard_func = 0;
byte hard_val = 0;
byte hard_ctrl[6] = {0,0,0,0,0,0};
boolean hard_shift = false;
unsigned long flashtick = 0;
boolean flashon = false;

#else /* PRODUCT */

#define HOLDLENGTH 2000     //time required to hold function button for hold functions (e.g. patch save)
#define LOCKOUT 3000        //time between ctrl stop moving and locking it out
byte hard_func = 255;         //current selected function. 255 to allow reset in Init_Hardware
byte hard_val[16];      //current select value for each function.
byte hard_ctrl[2][6];         //current value for each digital control [bank][control]
boolean hard_shift[16];       //current value of shift for each function (red/green mode)

#endif /* PRODUCT */

//long lastval;  //last value of value rotary encoder
byte maxval = 15;  //maximum value that is selectable on the value dial (normally 15 apart from user wave mode)
boolean testbutdown = false;  //test button (value encoder button)
byte hard_curctrlbank = 0;        //current value of ctrl bank (red/green mode of controls)
byte hard_curctrl = 1;            //current control being read.  Only 1 control is read in each pass.  read order:  0,1,0,2,0,3,0,4 etc, so cutoff is smooth as poss
byte hard_nextctrl = 1;           //sets next control to be read after cutoff.
byte lastfuncbut = 0;     //last value of function button input
byte lastvalbut = 0;      //last value of value button input
byte lastbank = 0;        //last value of ctrl bank button input
byte lastctrl[6];                 //last value read of each ctrl
// CPV - movingctrl and stopmovingtick don't seem to have a function anymore.
//boolean movingctrl[6];            //is a ctrl moving (i.e. is user turning it)
//unsigned long stopmovingtick[6];  //tick when ctrl will lock out (to stop jitter) assuming user has stopped moving it
unsigned long butstarttick = 0;   //tick when button was pressed
unsigned long ctrlstarttick = 0;   //tick when control was used
boolean finishedhold = false;     //used by function button for function that require 2 sec hold (e.g. patch save)
#if PRODUCT!=DELAYERTRON
boolean MIDIchannelmode = false;
#endif

void Hardware_Adjust_Value(byte func, byte val);
void Hardware_Adjust_Shift(byte func, boolean val);
boolean IsFuncFill(byte func);
boolean IsShiftHold(byte func);
int Hardware_Ctrl_Update(byte shift, byte index, int value);
void Hardware_reset_moving_ctrl(void);
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

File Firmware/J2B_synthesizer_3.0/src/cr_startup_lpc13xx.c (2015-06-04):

//*****************************************************************************
//   +--+       
//   | ++----+   
//   +-++    |  
//     |     |  
//   +-+--+  |   
//   | +--+--+  
//   +----+    Copyright (c) 2011-12 Code Red Technologies Ltd.
//
// Microcontroller Startup code for use with Red Suite
//
// Version : 120126
//
// Software License Agreement
// 
// The software is owned by Code Red Technologies and/or its suppliers, and is 
// protected under applicable copyright laws.  All rights are reserved.  Any 
// use in violation of the foregoing restrictions may subject the user to criminal 
// sanctions under applicable laws, as well as to civil liability for the breach 
// of the terms and conditions of this license.
// 
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
//*****************************************************************************
#if defined (__cplusplus)
#ifdef __REDLIB__
#error Redlib does not support C++
#else
//*****************************************************************************
//
// The entry point for the C++ library startup
//
//*****************************************************************************
extern "C" {
	extern void __libc_init_array(void);
}
#endif
#endif

#define WEAK __attribute__ ((weak))
#define ALIAS(f) __attribute__ ((weak, alias (#f)))
/* Include sys_config.h to get the CHIP_11* device identifier */
#include "sys_config.h"

// Code Red - if CMSIS is being used, then SystemInit() routine
// will be called by startup code rather than in application's main()
extern void SystemInit(void);

//*****************************************************************************
#if defined (__cplusplus)
extern "C" {
#endif

//*****************************************************************************
//
// Forward declaration of the default handlers. These are aliased.
// When the application defines a handler (with the same name), this will 
// automatically take precedence over these weak definitions
//
//*****************************************************************************
void ResetISR(void);
WEAK void NMI_Handler(void);
WEAK void HardFault_Handler(void);
WEAK void SVC_Handler(void);
WEAK void PendSV_Handler(void);
WEAK void SysTick_Handler(void);
WEAK void IntDefaultHandler(void);

//*****************************************************************************
//
// Forward declaration of the specific IRQ handlers. These are aliased
// to the IntDefaultHandler, which is a 'forever' loop. When the application
// defines a handler (with the same name), this will automatically take
// precedence over these weak definitions
//
//*****************************************************************************

#if defined(CHIP_LPC1343)
void WAKEUP_IRQHandler (void) ALIAS(IntDefaultHandler);
void I2C_IRQHandler (void) ALIAS(IntDefaultHandler);
void TIMER16_0_IRQHandler (void) ALIAS(IntDefaultHandler);
void TIMER16_1_IRQHandler (void) ALIAS(IntDefaultHandler);
void TIMER32_0_IRQHandler (void) ALIAS(IntDefaultHandler);
void TIMER32_1_IRQHandler (void) ALIAS(IntDefaultHandler);
void SSP0_IRQHandler (void) ALIAS(IntDefaultHandler);
void UART_IRQHandler (void) ALIAS(IntDefaultHandler);
void USB_IRQHandler (void) ALIAS(IntDefaultHandler);
void USB_FIQHandler (void) ALIAS(IntDefaultHandler);
void ADC_IRQHandler (void) ALIAS(IntDefaultHandler);
void WDT_IRQHandler (void) ALIAS(IntDefaultHandler);
void BOD_IRQHandler (void) ALIAS(IntDefaultHandler);
void FMC_IRQHandler (void) ALIAS(IntDefaultHandler);
void PIOINT3_IRQHandler (void) ALIAS(IntDefaultHandler);
void PIOINT2_IRQHandler (void) ALIAS(IntDefaultHandler);
void PIOINT1_IRQHandler (void) ALIAS(IntDefaultHandler);
void PIOINT0_IRQHandler (void) ALIAS(IntDefaultHandler);

#elif defined(CHIP_LPC1347)
void PIN_INT0_IRQHandler (void) ALIAS(IntDefaultHandler);
void PIN_INT1_IRQHandler (void) ALIAS(IntDefaultHandler);
void PIN_INT2_IRQHandler (void) ALIAS(IntDefaultHandler);
void PIN_INT3_IRQHandler (void) ALIAS(IntDefaultHandler);
void PIN_INT4_IRQHandler (void) ALIAS(IntDefaultHandler);
void PIN_INT5_IRQHandler (void) ALIAS(IntDefaultHandler);
void PIN_INT6_IRQHandler (void) ALIAS(IntDefaultHandler);
void PIN_INT7_IRQHandler (void) ALIAS(IntDefaultHandler);
void GINT0_IRQHandler (void) ALIAS(IntDefaultHandler);
void GINT1_IRQHandler (void) ALIAS(IntDefaultHandler);
void RIT_IRQHandler (void) ALIAS(IntDefaultHandler);
void SSP1_IRQHandler (void) ALIAS(IntDefaultHandler);
void I2C_IRQHandler (void) ALIAS(IntDefaultHandler);
void TIMER16_0_IRQHandler (void) ALIAS(IntDefaultHandler);
void TIMER16_1_IRQHandler (void) ALIAS(IntDefaultHandler);
void TIMER32_0_IRQHandler (void) ALIAS(IntDefaultHandler);
void TIMER32_1_IRQHandler (void) ALIAS(IntDefaultHandler);
void SSP0_IRQHandler (void) ALIAS(IntDefaultHandler);
void UART_IRQHandler (void) ALIAS(IntDefaultHandler);
void USB_IRQHandler (void) ALIAS(IntDefaultHandler);
void USB_FIQHandler (void) ALIAS(IntDefaultHandler);
void ADC_IRQHandler (void) ALIAS(IntDefaultHandler);
void WDT_IRQHandler (void) ALIAS(IntDefaultHandler);
void BOD_IRQHandler (void) ALIAS(IntDefaultHandler);
void FMC_IRQHandler (void) ALIAS(IntDefaultHandler);
void OSCFAIL_IRQHandler (void) ALIAS(IntDefaultHandler);
void PVTCIRCUIT_IRQHandler (void) ALIAS(IntDefaultHandler);
void USBWakeup_IRQHandler  (void) ALIAS(IntDefaultHandler);

#else
#error No CHIP_134* device defined  
#endif

//*****************************************************************************
//
// The entry point for the application.
// __main() is the entry point for redlib based applications
// main() is the entry point for newlib based applications
//
//*****************************************************************************
//
// The entry point for the application.
// __main() is the entry point for Redlib based applications
// main() is the entry point for Newlib based applications
//
//*****************************************************************************
#if defined (__REDLIB__)
extern void __main(void);
#endif
extern int main(void);
//*****************************************************************************
//
// External declaration for the pointer to the stack top from the Linker Script
//
//*****************************************************************************
extern void _vStackTop(void);

//*****************************************************************************
#if defined (__cplusplus)
} // extern "C"
#endif
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

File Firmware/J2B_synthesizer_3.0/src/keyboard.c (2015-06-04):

#include "atmegatron.h"


keyboard_key_t g_encoder[] =
{
	// Function bit 7 is either reserved 1 (IOCON_RESERVED_BIT_7) or "Digital functional mode" (IOCON_DIGMODE_EN),
	// meaning that it has to be set in all cases.
	// No pull-ups or -downs on rotary encoder pins. All inputs are inverted to read as 1 on contact closed.
	// Rotary encoders are handled as two non-matrix keys.

	#if defined BOARD_KEYBOARD_RE0 /* S1 */
		{ BOARD_KEYBOARD_RE0_A_PORT, BOARD_KEYBOARD_RE0_A_PIN, IOCON_DIGMODE_EN|IOCON_INV_EN },
		{ BOARD_KEYBOARD_RE0_B_PORT, BOARD_KEYBOARD_RE0_B_PIN, IOCON_DIGMODE_EN|IOCON_INV_EN },
	#endif

	#if defined BOARD_KEYBOARD_RE1 /* S2 */
		{ BOARD_KEYBOARD_RE1_A_PORT, BOARD_KEYBOARD_RE1_A_PIN, IOCON_DIGMODE_EN|IOCON_INV_EN },
		{ BOARD_KEYBOARD_RE1_B_PORT, BOARD_KEYBOARD_RE1_B_PIN, IOCON_DIGMODE_EN|IOCON_INV_EN },
	#endif

	#if defined BOARD_KEYBOARD_RE2 /* S3 */
		{ BOARD_KEYBOARD_RE2_A_PORT, BOARD_KEYBOARD_RE2_A_PIN, IOCON_DIGMODE_EN|IOCON_INV_EN },
		{ BOARD_KEYBOARD_RE2_B_PORT, BOARD_KEYBOARD_RE2_B_PIN, IOCON_FUNC1|IOCON_DIGMODE_EN|IOCON_INV_EN },
	#endif

	#if defined BOARD_KEYBOARD_RE3 /* S4 */
		{ BOARD_KEYBOARD_RE3_A_PORT, BOARD_KEYBOARD_RE3_A_PIN, IOCON_DIGMODE_EN|IOCON_INV_EN },
		{ BOARD_KEYBOARD_RE3_B_PORT, BOARD_KEYBOARD_RE3_B_PIN, IOCON_FUNC1|IOCON_DIGMODE_EN|IOCON_INV_EN },
	#endif

	#if defined BOARD_KEYBOARD_RE4 /* S5 */
		{ BOARD_KEYBOARD_RE4_A_PORT, BOARD_KEYBOARD_RE4_A_PIN, IOCON_DIGMODE_EN|IOCON_INV_EN },
		{ BOARD_KEYBOARD_RE4_B_PORT, BOARD_KEYBOARD_RE4_B_PIN, IOCON_FUNC1|IOCON_DIGMODE_EN|IOCON_INV_EN },
	#endif

	#if defined BOARD_KEYBOARD_RE5 /* S6 */
		{ BOARD_KEYBOARD_RE5_A_PORT, BOARD_KEYBOARD_RE5_A_PIN, IOCON_DIGMODE_EN|IOCON_INV_EN },
		{ BOARD_KEYBOARD_RE5_B_PORT, BOARD_KEYBOARD_RE5_B_PIN, IOCON_DIGMODE_EN|IOCON_INV_EN },
	#endif

	#if defined BOARD_KEYBOARD_RE6 /* S7 */
		{ BOARD_KEYBOARD_RE6_A_PORT, BOARD_KEYBOARD_RE6_A_PIN, IOCON_DIGMODE_EN|IOCON_INV_EN },
		{ BOARD_KEYBOARD_RE6_B_PORT, BOARD_KEYBOARD_RE6_B_PIN, IOCON_DIGMODE_EN|IOCON_INV_EN },
	#endif

	#if defined BOARD_KEYBOARD_RE7 /* S8 */
		{ BOARD_KEYBOARD_RE7_A_PORT, BOARD_KEYBOARD_RE7_A_PIN, IOCON_DIGMODE_EN|IOCON_INV_EN },
		{ BOARD_KEYBOARD_RE7_B_PORT, BOARD_KEYBOARD_RE7_B_PIN, IOCON_DIGMODE_EN|IOCON_INV_EN },
	#endif
};
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

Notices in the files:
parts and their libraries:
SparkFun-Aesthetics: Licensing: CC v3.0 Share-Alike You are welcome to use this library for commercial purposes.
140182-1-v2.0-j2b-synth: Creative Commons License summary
